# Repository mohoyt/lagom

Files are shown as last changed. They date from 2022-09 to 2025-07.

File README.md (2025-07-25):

# lagom
Lagom is an easy to build 65% keyboard using only through hole components. It uses a separate microcontroller (like the Pro Micro, Elite C or something RP2040 based) to enable flexibility in firmware and connectivity and to further simplify the soldering experience (no more tricksy USB ports). Demultiplexers and a custom matrix are used to enable the size and features of the board with only the pinouts of a pro micro. 

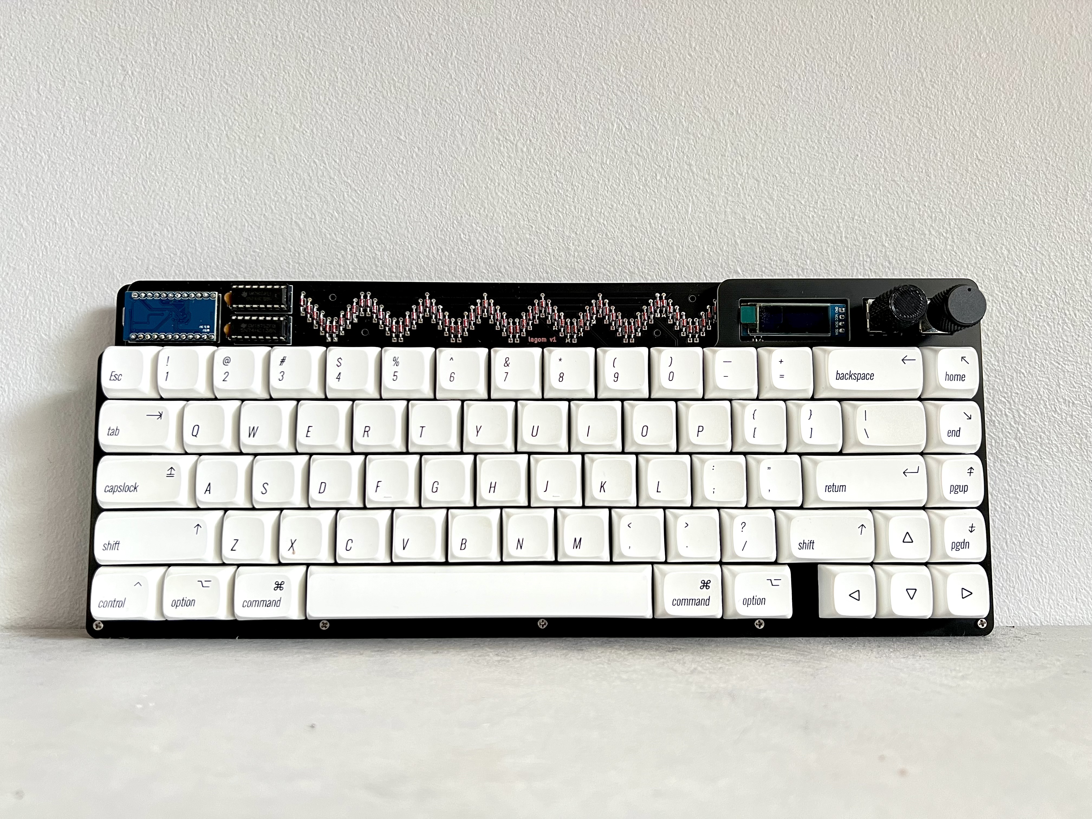
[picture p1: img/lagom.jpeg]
lagom


**Lagom kits are available for sale at [sthlmkb.com](https://sthlmkb.com/shop/lagom-keyboard-kit/)**

[License](LICENSE)

Lagom is licensed under the [Creative Commons Attribution-NonCommercial 4.0 International license](https://creativecommons.org/licenses/by-nc/4.0/). This design as it stands in this repository may be freely reproduced, modified, and manufactured for PERSONAL USE ONLY and may not be reproduced in physical form for public sale. 

## Features
* Only through hole components for easy soldering
* Separate microcontroller using Pro micro, Elite C, Nice! Nano or equivalent footprint. So micro USB, USB-C or Bluetooth are all options!
* 2 rotary encoders
* OLED screen
* Optional underglow RGB lighting with a WS2812b light strip
* Multiple layout options including ISO, ANSI, split space (2.25u + 1.25u + 2.75u), 7u space, split left shift (1.25u + 1u) and stepped capslock ([layout]("http://www.keyboard-layout-editor.com/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,15&_x:0.25%3B&=2,15&_x:0.25%3B&=0,0%0A%0A%0A%0A%0A%0A%0A%0A%0Ae&=0,1%0A%0A%0A%0A%0A%0A%0A%0A%0Ae%3B&@_y:0.25%3B&=0,0&=0,1&=0,2&=0,3&=0,4&=0,5&=0,6&=0,7&=0,8&=0,9&=0,10&=0,11&=0,12&_w:2%3B&=0,14%0A%0A%0A0,0&=0,15&_x:0.25%3B&=1,0%0A%0A%0A%0A%0A%0A%0A%0A%0Ae&=1,1%0A%0A%0A%0A%0A%0A%0A%0A%0Ae%3B&@_w:1.5%3B&=1,0&=1,1&=1,2&=1,3&=1,4&=1,5&=1,6&=1,7&=1,8&=1,9&=1,10&=1,11&=1,12&_w:1.5%3B&=1,13%0A%0A%0A1,0&=1,14%3B&@_w:1.75%3B&=2,0&=2,1&=2,2&=2,3&=2,4&=2,5&=2,6&=2,7&=2,8&=2,9&=2,10&=2,11&_w:2.25%3B&=2,13%0A%0A%0A1,0&=2,14%3B&@_w:2.25%3B&=3,0%0A%0A%0A2,0&=3,2&=3,3&=3,4&=3,5&=3,6&=3,7&=3,8&=3,9&=3,10&=3,11&_w:1.75%3B&=3,12&=3,13&=3,14%3B&@_w:1.25%3B&=4,0%0A%0A%0A3,0&_w:1.25%3B&=4,1%0A%0A%0A3,0&_w:1.25%3B&=4,2%0A%0A%0A3,0&_w:6.25%3B&=4,6%0A%0A%0A3,0&_w:1.25%3B&=4,10%0A%0A%0A3,0&_w:1.25%3B&=4,11%0A%0A%0A3,0&_x:0.5%3B&=4,12&=4,13&=4,14%3B&@_y:0.5&w:1.25%3B&=4,0%0A%0A%0A3,1&_w:1.25%3B&=4,1%0A%0A%0A3,1&_w:1.25%3B&=4,2%0A%0A%0A3,1&_w:2.25%3B&=4,4%0A%0A%0A3,1&_w:1.25%3B&=4,6%0A%0A%0A3,1&_w:2.75%3B&=4,8%0A%0A%0A3,1&_w:1.25%3B&=4,10%0A%0A%0A3,1&_w:1.25%3B&=4,11%0A%0A%0A3,1%3B&@_y:-0.25&x:15&w:1.25&h:2&w2:1.5&h2:1&x2:-0.25%3B&=2,13%0A%0A%0A1,1%3B&@_y:-0.75&w:1.5%3B&=4,0%0A%0A%0A3,2&=4,1%0A%0A%0A3,2&_w:1.5%3B&=4,2%0A%0A%0A3,2&_w:7%3B&=4,6%0A%0A%0A3,2&_w:1.5%3B&=4,11%0A%0A%0A3,2%3B&@_y:-0.25&x:14%3B&=2,12%0A%0A%0A1,1%3B&@_w:1.25%3B&=3,0%0A%0A%0A2,1&=3,1%0A%0A%0A2,1&_x:9.75%3B&=0,13%0A%0A%0A0,1&=0,14%0A%0A%0A0,1"))
* Open and visible components (in the style of Plaid, Romac etc)
* Simple, beautiful and flexible sandwich case out of FR4 (pcb material)

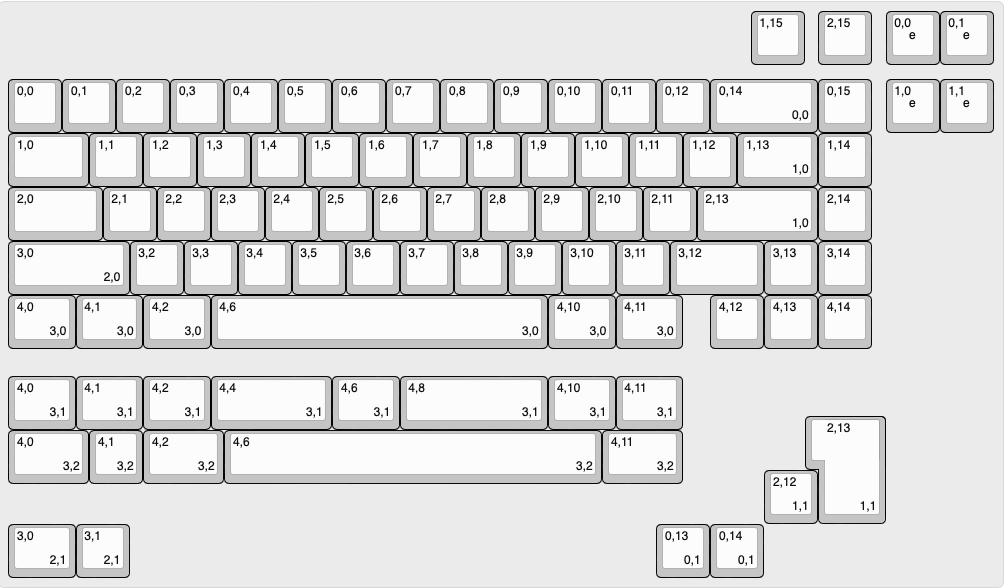
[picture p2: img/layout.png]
lagom layout


## Components required 
* PCB
* FR4 Switch plate
* FR4 Base 
* Controller (I used a Pro Micro in the guide but anything that shares the footprint and pinout will be fine e.g. Elite C, Nice! Nano, or something RP2040 powered!)
* Diodes 1N4148 (74)
* 0.1μF Capacitor (2)
* 16 pin IC socket (2)
* IC (74HC138N) demultiplexer (2)
* Switches (5 pin MX footprint) (up to 72 depending on layout)
* Rotary encoders (2)
* Rotary encoder knobs (2)
* 0.91" OLED screen
* 10mm M2 Standoffs (9 required if mounting the base to the plate)
* 6mm x M2 screws for attaching the standoffs to the plate/base (2 per standoff so 18 total)
* Acrylic cover for the components at the top (optional, not included)
* Stabilisers (PCB mount) (5 x 2u or 3 x 2u + 6.25u or 3 x 2u + 7u depending on layout)
* Rubber feet for the base

[Build guide available here](build_guide.md)

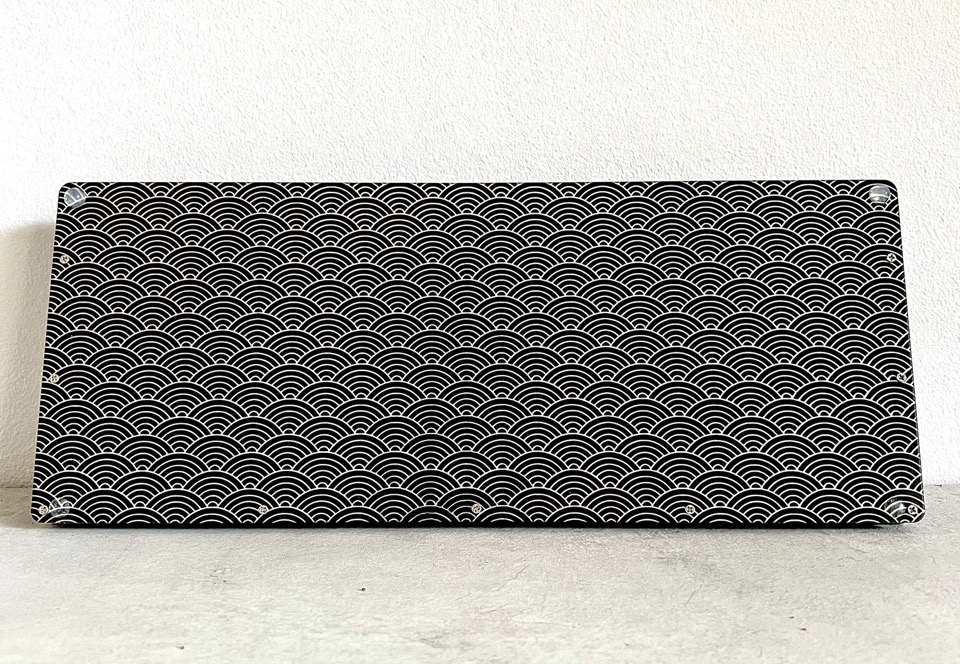
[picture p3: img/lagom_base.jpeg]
lagom base


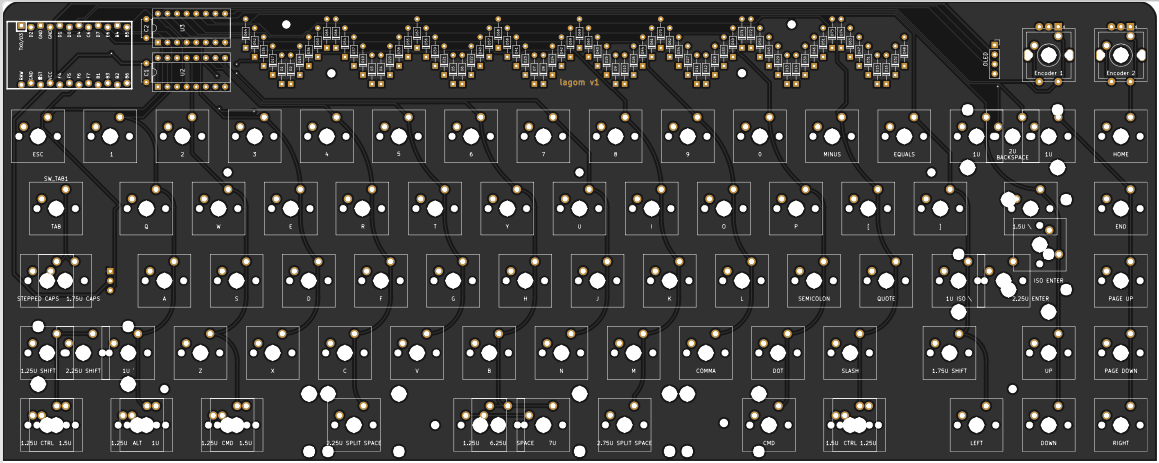
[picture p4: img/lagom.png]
lagom lagom pcb


## Dimensions
* PCB: 305.6mm x 121.78mm
* Plate: 319.925mm x 128.925mm (102.662mm height at the lower section)
* Base: 319.925mm x 128.925mm 

## Known issues 
None yet! 

## Where to buy
Lagom kits are available for sale exclusively at [sthlmkb.com](https://sthlmkb.com/shop/lagom-keyboard-kit/)

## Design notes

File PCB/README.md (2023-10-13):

# lagom PCBs
Lagom is an easy to build 65% keyboard using only through hole components. It uses a separate microcontroller (like the Pro Micro, Elite C or something RP2040 based) to enable flexibility in firmware and connectivity and to further simplify the soldering experience (no more tricksy USB ports). Demultiplexers and a custom matrix are used to enable the size and features of the board with only the pinouts of a pro micro. 

lagom

**Lagom kits are available for sale at [sthlmkb.com](https://sthlmkb.com/shop/lagom-keyboard-kit/)**

[License](LICENSE)

Lagom is licensed under the [Creative Commons Attribution-NonCommercial 4.0 International license](https://creativecommons.org/licenses/by-nc/4.0/). This design as it stands in this repository may be freely reproduced, modified, and manufactured for PERSONAL USE ONLY and may not be reproduced in physical form for public sale. 

## Designs that are here:
* Lagom (i.e this directory) - this is the main PCB
* Lagom Plate (`lagom_plate`) - this is the plate that holds the switches and goes above the PCB
* Lagom Base (`lagom_base`) - this is the base of the board and goes below the PCB
* Lagom Window (`lagom_window`) - this is an optional design for an acrylic window that covers the diodes and the controller

## Some useful images/documentation:

lagom layout

This the key layout and all option layouts exported from keyboard-layout-editor

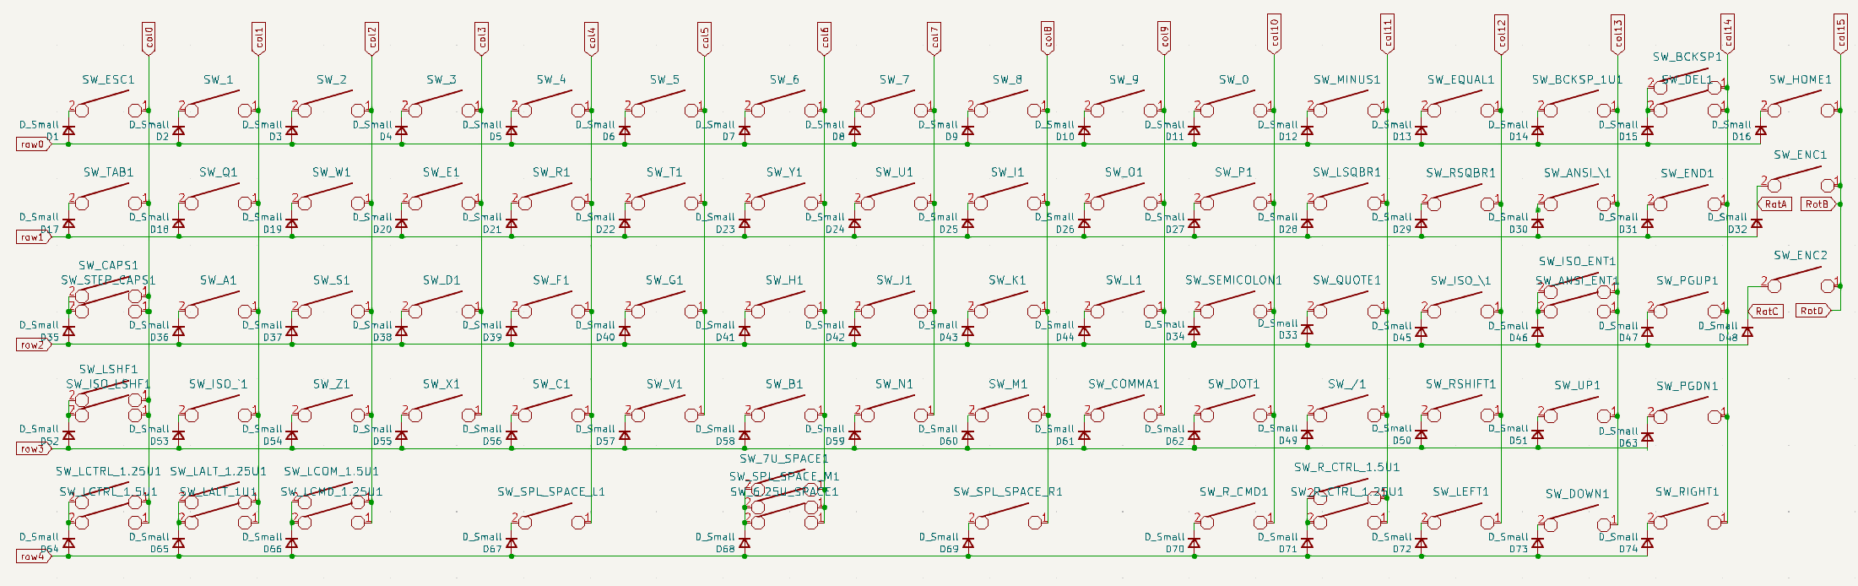
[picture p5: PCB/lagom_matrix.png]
lagom matrix


This the layout of the matrix used

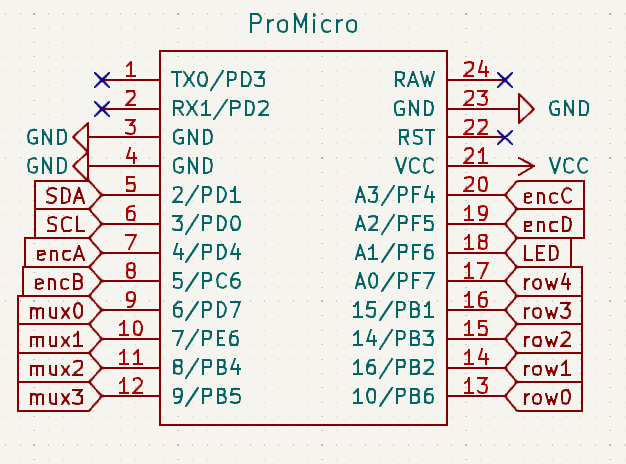
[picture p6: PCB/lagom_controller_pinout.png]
controller pinout


This the pinout of the pro micro or pro micro compatible controller

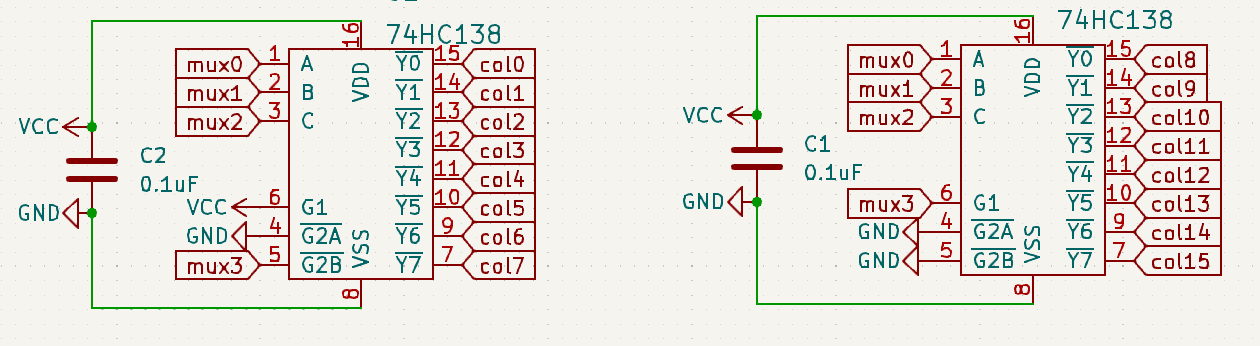
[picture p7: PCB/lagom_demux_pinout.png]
demux pinout


This is the pinout of the demuxes used in Lagom to enable all the columns to work on a pro micro pinout

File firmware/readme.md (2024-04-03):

# lagom

Lagom is an easy to build 65%ish keyboard using only through hole components. It uses a separate microcontroller (like the Pro Micro or Elite C) to enable flexibility in connectivity and to further simplify the soldering experience (no more tricksy USB ports).

* Keyboard Maintainer: [mohoyt](https://github.com/mohoyt)
* Hardware Supported: lagom, Pro Micro, Elite-C, Puchi-C, Nice!Nano and more...
* Hardware Availability: [sthlm kb](https://sthlmkb.com)

Make example for this keyboard (after setting up your build environment):

    make sthlmkb/lagom:default

See the [build environment setup](https://docs.qmk.fm/#/getting_started_build_tools) and the [make instructions](https://docs.qmk.fm/#/getting_started_make_guide) for more information. Brand new to QMK? Start with our [Complete Newbs Guide](https://docs.qmk.fm/#/newbs).

NB If you want to flash a Vial compatible image then you have to use the [Vial fork of QMK](https://github.com/vial-kb/vial-qmk) and ensure that you have all the Vial specific files present (but these should already be there if you're using on the Vial keymaps as a starting point).

Alternatively flash one of the precompiled hexes. There's a few options:
* One's a Vial compatible image one with bongocat
* Another's a Vial image with a WPM graph on it

The .hex file is if you're using an Atmel chip (like a traditional Pro Micro). The uf2 files are for a RP2040 style pro micro like the Helios. 

## RP2040 Flashing

If you are compiling your own firmware for a RP2040 variant of a Pro Micro then the easiest way of converting the output from .hex to .uf2 is to use the convert feature of QMK [more details here](https://docs.qmk.fm/#/feature_converters?id=overview). 

For example you would flash one with a Helios style pin out like this:
```
make sthlmkb/lagom:vial-wpmhud CONVERT_TO=helios
```

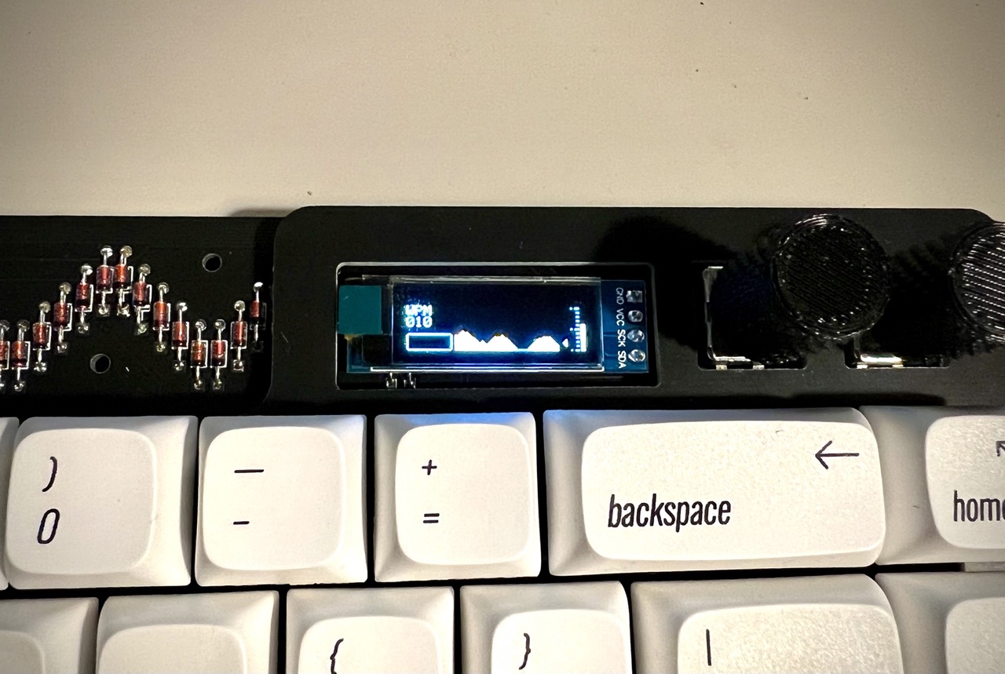
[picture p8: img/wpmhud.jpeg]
wpm graph lagom


## RGB Lighting

It is possible to add RGB lighting to the Lagom. There's a couple changes that you need to make to info.json to make it happen before recompiling the firmware. These changes are:
* Adding `"rgblight": true` to the feature section
* Adding a `rgblight` and `ws2812` section. More info [here](https://docs.qmk.fm/#/feature_rgblight) too.
```    
"rgblight": {
        "led_count": 11,
        "sleep": true,
        "hue_steps": 10,
        "saturation_steps": 10,
        "brightness_steps": 10,
        "animations": {
            "rainbow_mood": true,
            "static_gradient": true
        }
       },
    "ws2812": {
        "pin": "F6"
        }
```
* You'll then need to assign some keys to toggle on the RGB and change modes etc. This is easiest done in Vial if you've flashed a Vial compatible image. 
* Bear in mind that the RGB feature takes up some space so you may run out of space if you're compiling this for a Pro Micro

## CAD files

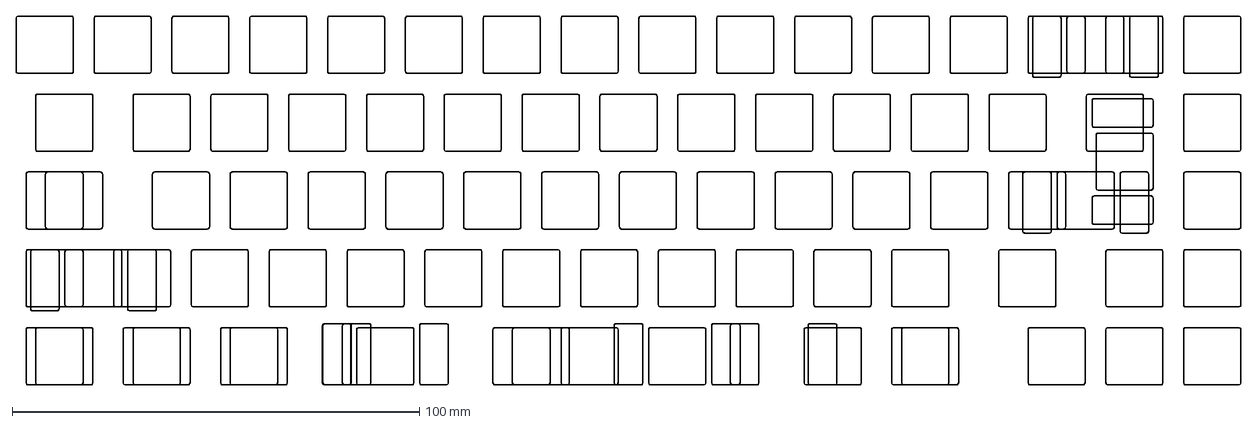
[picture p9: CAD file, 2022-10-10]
PCB/lagom-plate-orig.dxf
300.5 x 90.4 mm

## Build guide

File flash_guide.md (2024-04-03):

# Pro Micro Microcontroller Flashing Guide

You’ve built your keyboard and now you want to make it work. To do this you’ll have to flash your microcontroller.

The exact specfics of how you do this depend on the microcontroller that you’re using, so take a look at their specific documentation. I will go through the process of flashing a Pro Micro conroller here. The instructions assume that you’re flashing a ‘traditional’ atmel based Pro Micro, but if you are flashing a RP2040 variant then scroll down to the lower section of this page.

## Atmel ‘Traditional’ Pro Micro Flashing

1. You’ll need a compiled firmware file. This is something that you might have downloaded from where you bought your keyboard, or something that you configured and built yourself. It’s a file that has a .hex file format. We have precompiled firmware files for Lagom [here](https://github.com/mohoyt/lagom/releases) and some notes on compiling [here](https://github.com/mohoyt/lagom/firmware).

2. Download and install QMK Toolbox from their Github page: https://github.com/qmk/qmk_toolbox

3. Open QMK Toolbox and connect your keyboard or controller to your computer over USB. You might see something in the QMK console when you connect it, but not always.

4. Press open at the top of the QMK configurator window and choose the .hex file that you want to flash to your microcontroller. Precompiled (and Vial compatible) hex files for the Lagom are available [here on our Github](https://github.com/mohoyt/lagom/releases). If you want to be able to configure your keyboard using Vial (recommended) then make sure to flash one of the vial hex files. Ensure that the file that you’re trying to flash has the file format .hex as sometimes browsers will download these files oddly. 

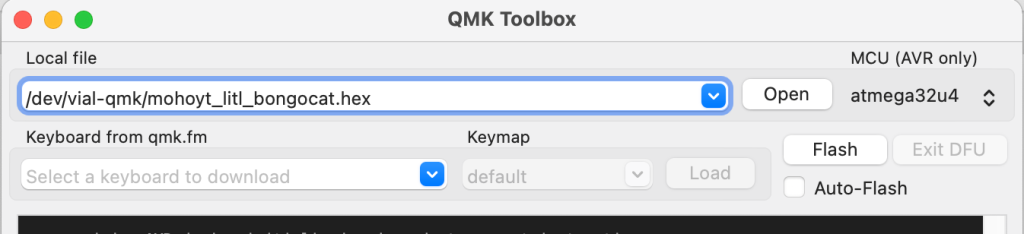
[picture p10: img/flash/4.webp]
qmk toolbox


5. Ensure that you have the correct MCU chosen at the top right of the QMK Toolbox window. For a Pro Micro it is an atmega32u4

6. Now comes the slightly tricky bit. You’ll need something metal to short two of the pins on the microcontroller. You can use pliers, a piece of wire or even a pen. You want to briefly connect and then disconnect the RESET and the GROUND pins of the Pro Micro. These are the second and third pins on the right hand side when the components are facings towards you and the usb port is facing up.

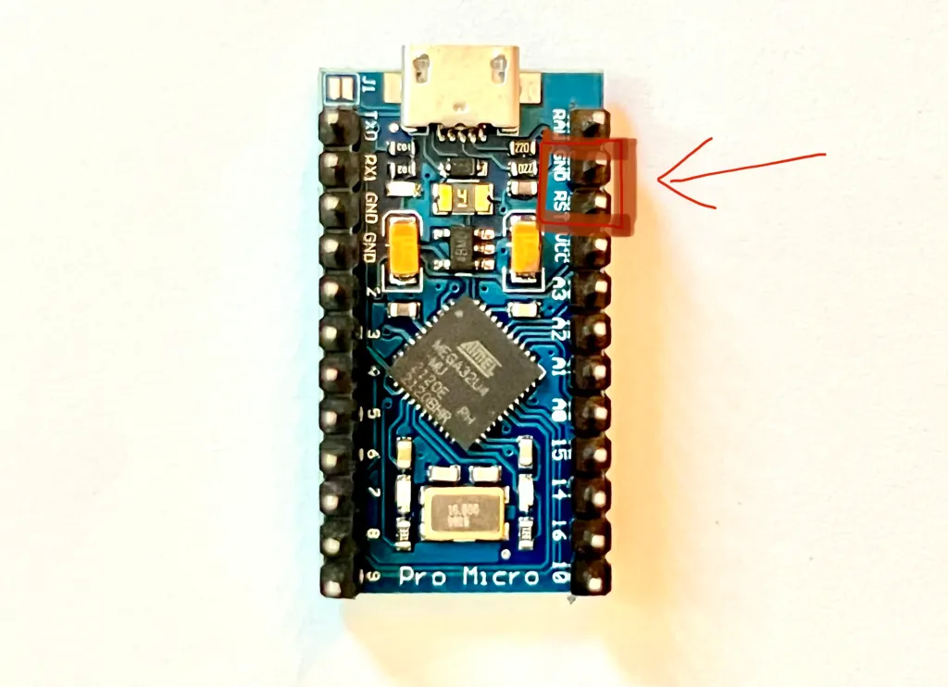
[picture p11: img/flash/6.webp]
pro micro pins


If you’re flashing the controller once it’s already soldered on the keyboard then you will need to short the same pins but likely from the other side. It’s the two pins pictured in the image below.

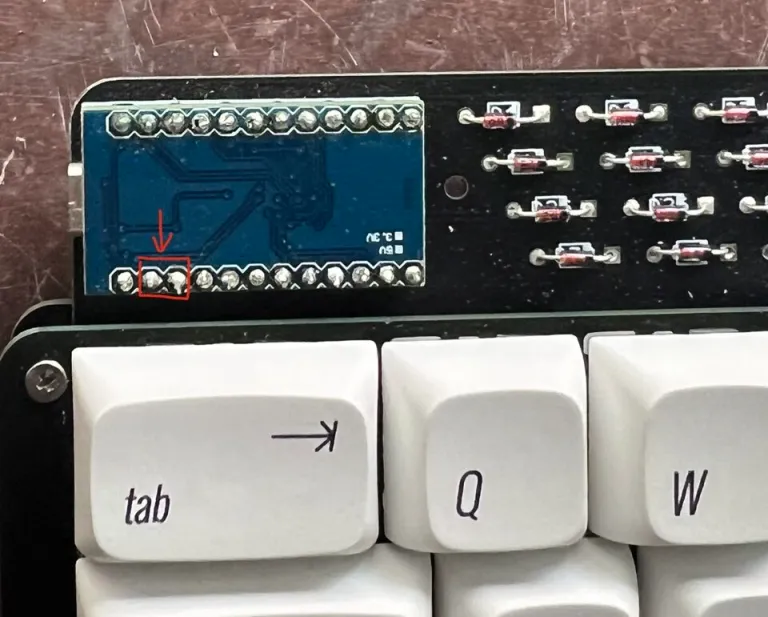
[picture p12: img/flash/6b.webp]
pro micro pins on board


7. If you’ve successfully connected the pins and then disconnected them you should see a yellow line in the QMK Toolbox console like this. The line might say something slightly different depending on your controller.

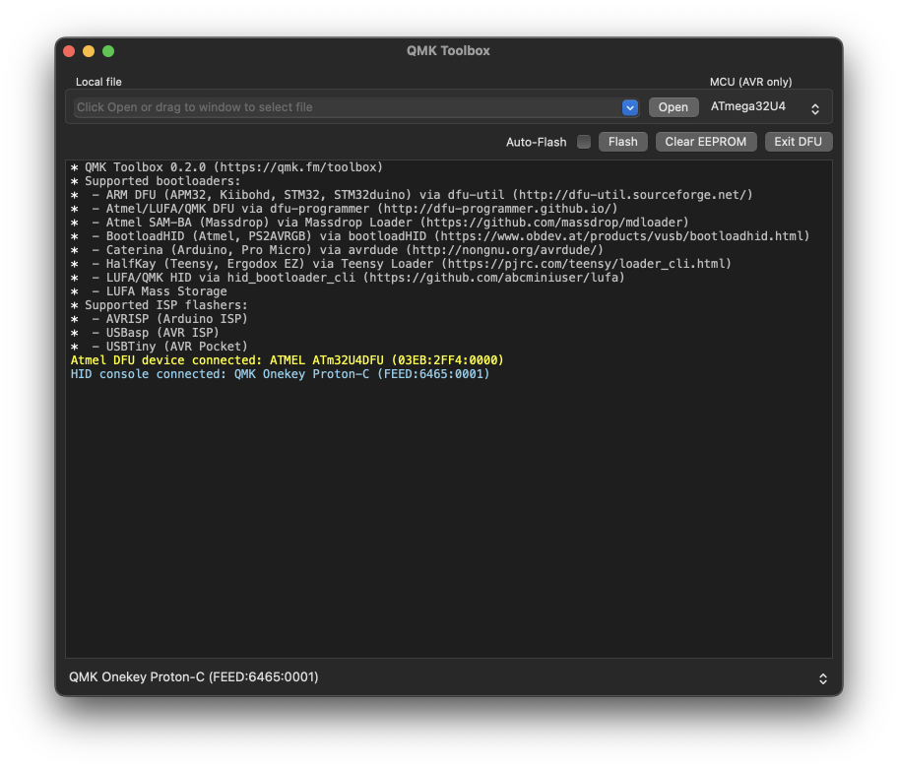
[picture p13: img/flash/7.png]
qmk toolbox screenshot


8. Once you see the yellow line, you need to press Flash within 5 seconds. There will be lots of text rendered on the console when you do this, but it will ultimately say something like avrdude done. Thank you  and then will print another yellow disconnect line if it succeeds.

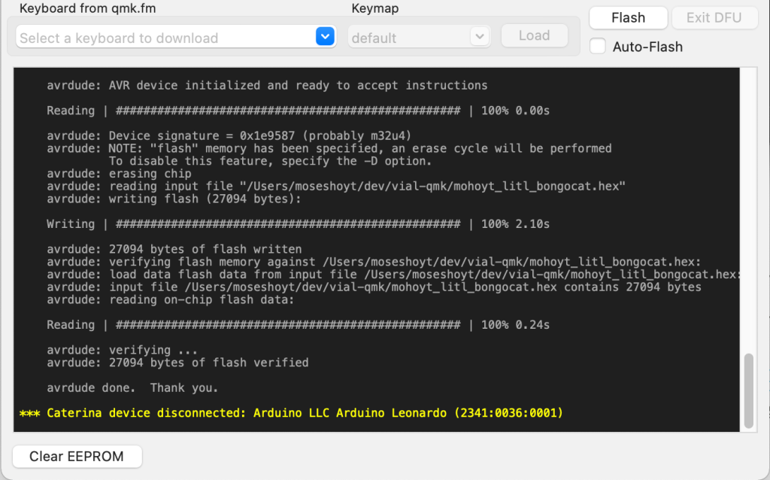
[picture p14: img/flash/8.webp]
successful flash


9. If you’ve flashed the QMK firmware then your keyboard should be good to go right away. If you flashed the Vial firmware then your keyboard should work right away too, but if you want to configure layers then you will have to download Vial.

## RP2040 Pro Micro Flashing

1. You’ll need a compiled firmware file. This is something that you might have downloaded from where you bought your keyboard, or something that you configured and built yourself. It’s a file that has a .uf2 file format. We have precompiled firmware files for Lagom [here](https://github.com/mohoyt/lagom/releases) and some notes on compiling [here](https://github.com/mohoyt/lagom/firmware).

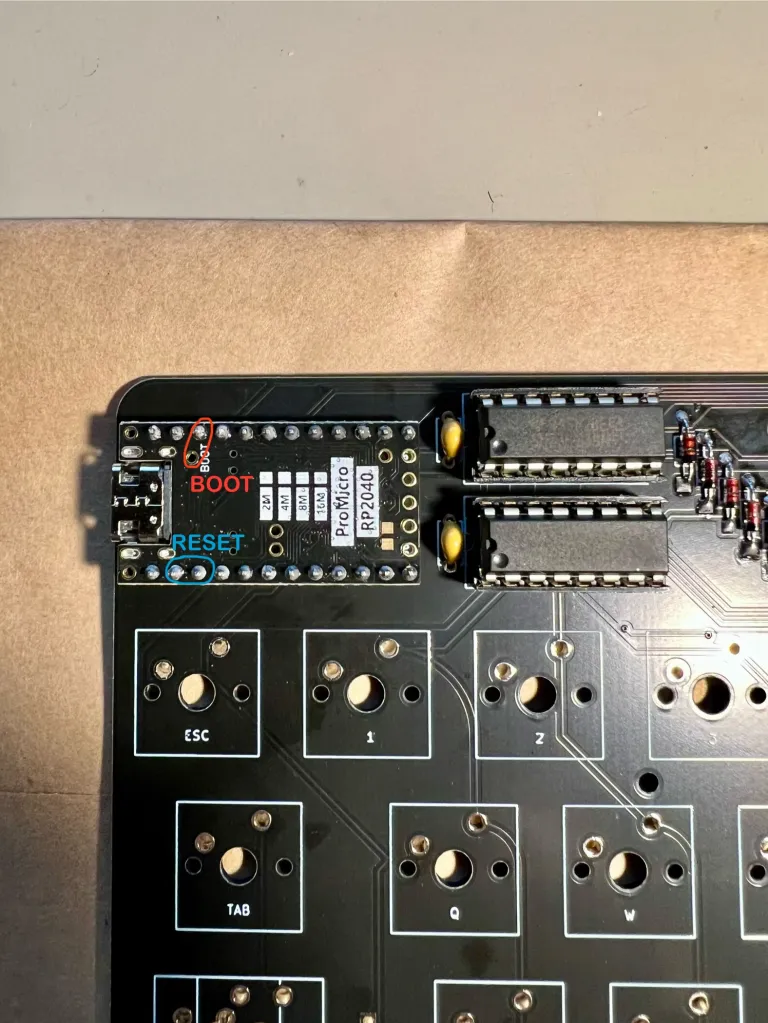
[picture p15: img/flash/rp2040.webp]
rp2040 flash


2. You now need to plug it in with USB to your computer and get the RP2040 Pro Micro to enter bootloader mode.

The RP2040 will be in bootloader mode when a RPI-RP2 volume appears on your computer.

There are a number of ways of doing this. Ranked from easy to most tricky:

* If you have a brand new RP2040 Pro Micro, many times it will start up for the first time in bootloader mode. But if not, read on.
* If you have a built keyboard – hold down the bootloader key while you plug in the keyboard.
    * This is the easiest way to get into the bootloader. But it only works if the controller is already flashed with QMK or Vial. The key you would need to hold down is the key is the first key on the first column. 99% of the time that’s the escape key.
* If you have the Pro Micro unconnected to a keyboard or the reset button easily accessible – double tap the reset button on the Pro Micro RP2040.
    * Like the method above this only works if it is already flashed with QMK. This is a little bit more annoying than holding down a key because you may need to open your keyboards case to gain access to your reset switch.
    * If there is no reset button then you can short the RST pin and a GND pin twice in quick succession.
* Hold down the boot button on the Pro Micro RP2040 while you plug in your keyboard.
    * The Pro Micro RP2040 has 2 buttons on it, boot and reset. Hold boot in while connecting via USB
    * You can also short the BOOT pin and a GND pin while plugging in the keyboard too
* Hold down boot switch while you tap your reset switch.
    * If you have access to both BOOT and RESET switches (e.g. if you’ve not soldered on the Pro Micro yet) you simply hold down the boot switch while you tap and let go of the reset switch.
    * You can also short and hold the BOOT pin and a GND pin while shorting RST and a GND pin to achieve the same thing.

*You will know that these work when a RPI-RP2 drive is mounted on your computer.*

3. Drag the .uf2 firmware file to the RPI-RP2 drive that has now been mounted on your computer. Once the file is copied the drive should automatically disconnect.

4. You may have to unplug and re plug in the controller, but it should now be recognised to you computer as a keyboard (or input device) and you should be able to type on it.

## You did it! Nice one. 

Any feedback or challenges with the build process? Get in touch with us at hej at sthlmkb.com

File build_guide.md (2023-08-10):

# Lagom build guide

lagom

## Components required 

* PCB
* FR4 Switch plate
* FR4 Base 
* Controller (I used a Pro Micro in the guide but anything that shares the footprint and pinout will be fine e.g. Elite C, Nice! Nano, or something RP2040 powered!)
* Diodes 1N4148 (74)
* 0.1μF Capacitor (2)
* 16 pin IC socket (2)
* IC (74HC138N) demultiplexer (2)
* Switches (5 pin MX footprint) (up to 72 depending on layout)
* Rotary encoders (2)
* Rotary encoder knobs (2)
* 0.91" OLED screen
* 10mm M2 Standoffs (9 required if mounting the base to the plate)
* 6mm x M2 screws for attaching the standoffs to the plate/base (2 per standoff so 18 total)
* Acrylic cover for the components at the top (optional, not included)
* Stabilisers (PCB mount) (5 x 2u or 3 x 2u + 6.25u or 3 x 2u + 7u depending on layout)
* Rubber feet for the base

## You will also need

* Soldering iron
* Solder
* Diode bender (helpful but not required, I used [this one](https://www.printables.com/model/23523-1n4148-diodes-bending-jig))
* A small amount of electrical tape for the backside of the OLED

## Before you begin!

Please double check everything and that you have all the parts! If you ordered a kit there is a very slim chance we forgot something or that your order is wrong; in the case this is true, please reach out via email at hej at sthlmkb.com and we will work with you to make it right. 

Due to the DIY nature of this hobby, as soon as a soldering iron touches or other modifications happen to the board, I am no longer able to issue a refund/replacement. 

Note about this guide: For this guide, I am building a board with a Pro Micro, 2 encoders and an OLED - yours may differ. You are free to adjust or skip steps if they do not apply to your scenario.

All that being said, let's get started!

## Step by step

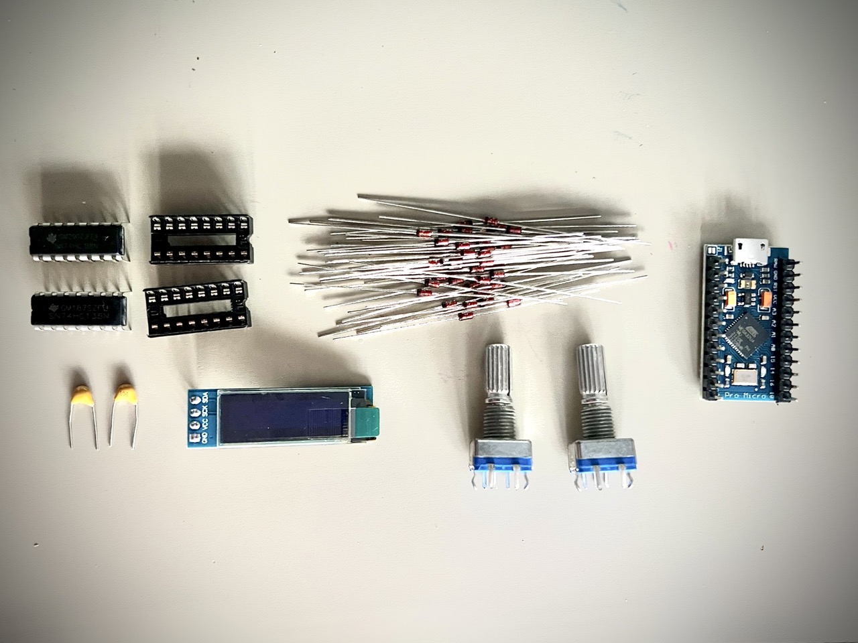
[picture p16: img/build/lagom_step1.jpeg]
components

1. Check that you have all the components you need.

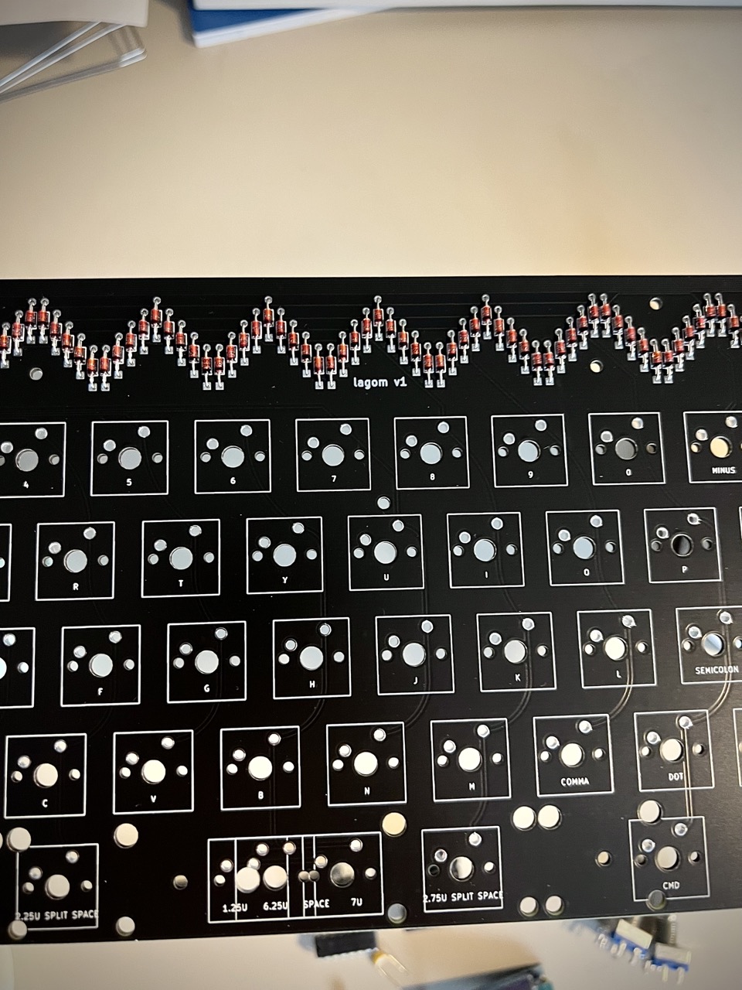
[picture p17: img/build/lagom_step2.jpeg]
diodes

2. Start by bending all the diodes (I used the 3d printed diode bender above). And then place them in the sockets, ensuring that you have the *correct orientation*, the black line on the diode should match the white lines on the board. I then placed some tape over the diodes to hold them in place while I flipped over the board to solder them.

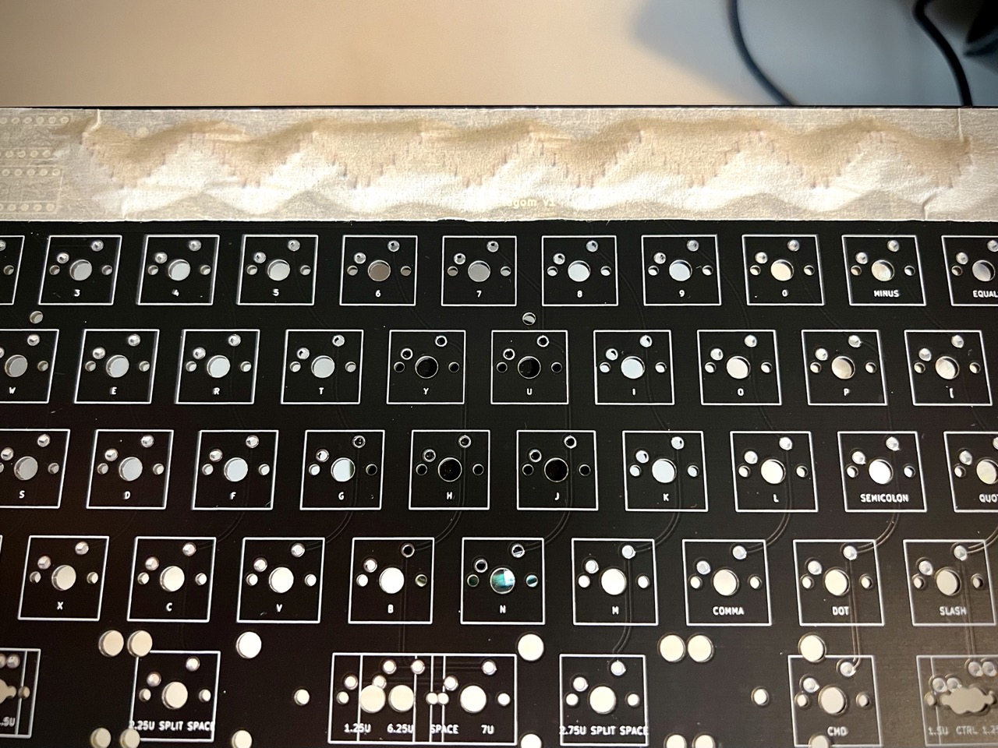
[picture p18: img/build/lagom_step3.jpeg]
masking tape on diodes

3. Solder the diodes on (I soldered on the underside of the board) and trim their legs once the solder has cooled

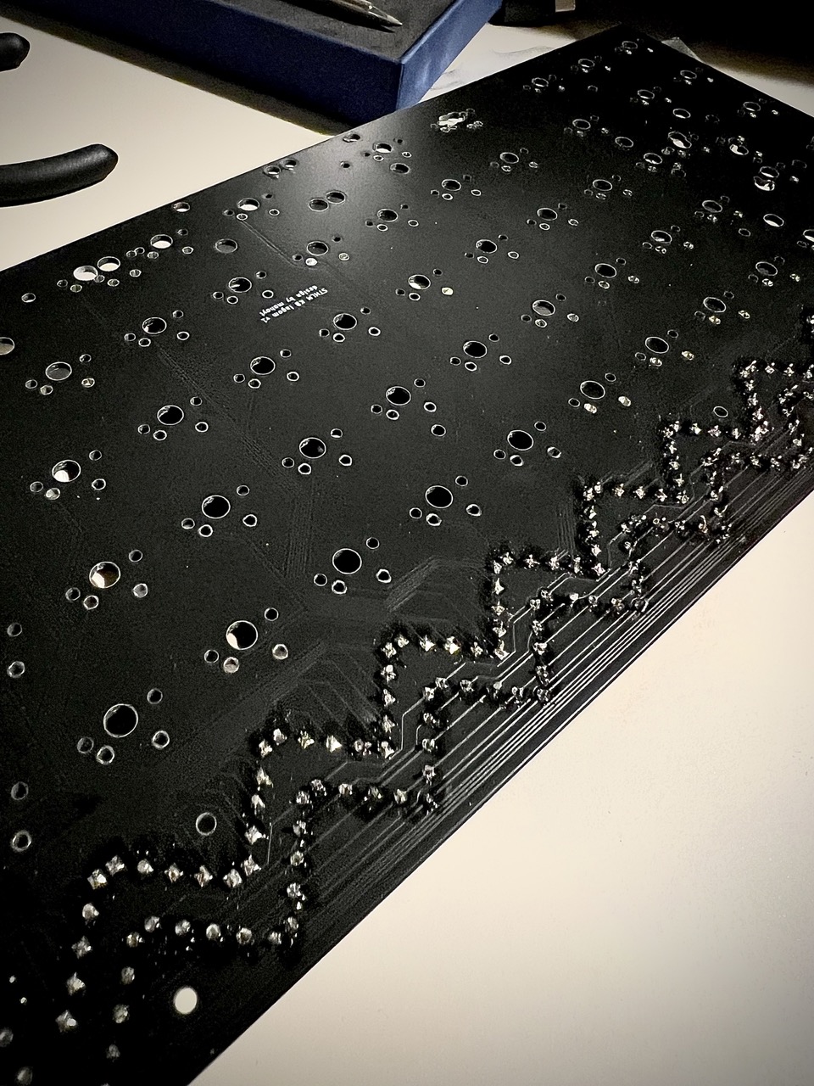
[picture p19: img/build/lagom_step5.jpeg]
trimmed legs

4. Solder the 2 capacitors to the PCB. They should sit on the top side of the PCB (like the diodes). Orientation does not matter with them.

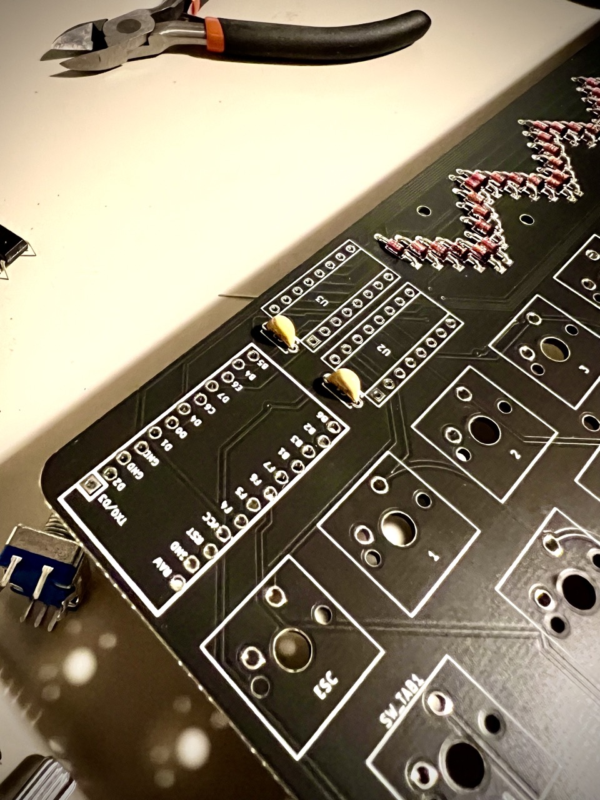
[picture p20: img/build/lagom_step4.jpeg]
capacitors

5. Solder the 2 IC sockets to the PCB. They have a notch on them and the notch should be aligned with the notch on the footprint (pointing towards the capacitors). Do *not* place the ICs in the sockets yet. 

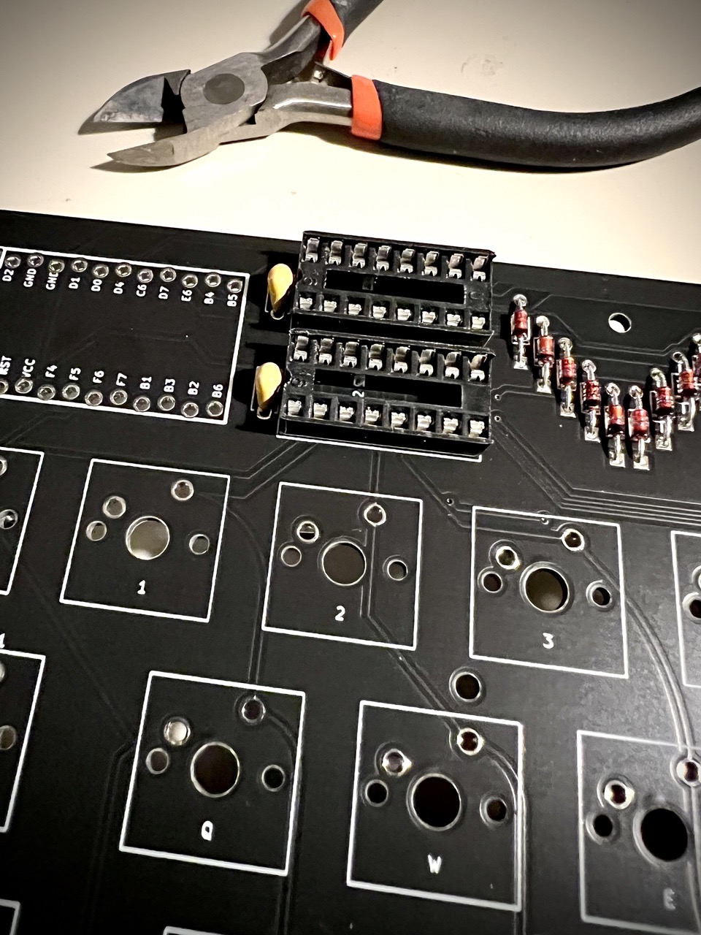
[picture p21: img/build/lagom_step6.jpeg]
ic sockets

6. Solder the two rotary encoders to the board. They should only fit one way, ensure that you don't bend any of the pins when doing so.

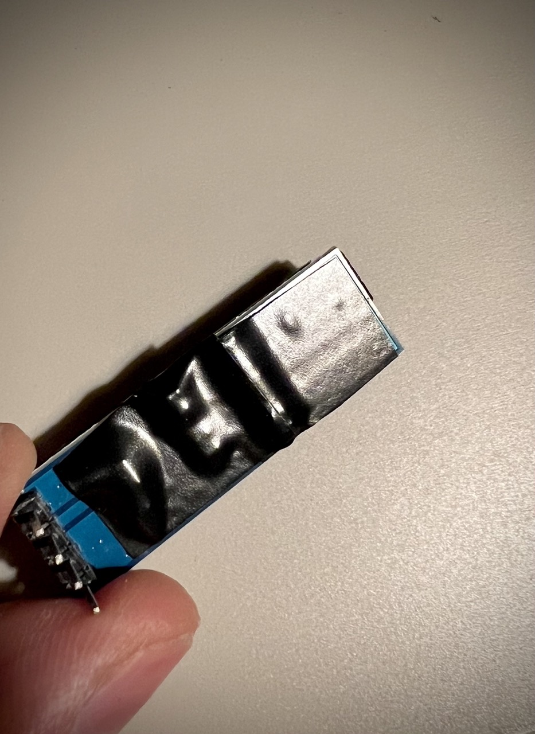
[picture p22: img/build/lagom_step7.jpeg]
oled tape


7. Cut a small section or two of electrical tape and place it on the back of the OLED screen to cover up the resistors and other surface mount components there. This is to ensure that they do not short with the diodes when placed on top of them.
8. Solder the OLED screen in place. The screen should be facing to the left and the ground pin of the OLED should be at the top of the board. The orientation matters here, but realistically it's hard to get it wrong as the encoders will be in the way. If you're planning on adding RGB underglow with a light strip (e.g. a WS2812b compatible one) then this is could be a good time to solder a socket to the 3 holes to make it easier for later (but it's possible to mod this later if you want to). See the image below for an example (excuse the poor soldering). Ensure you get the pins correct when you add an LED strip. 

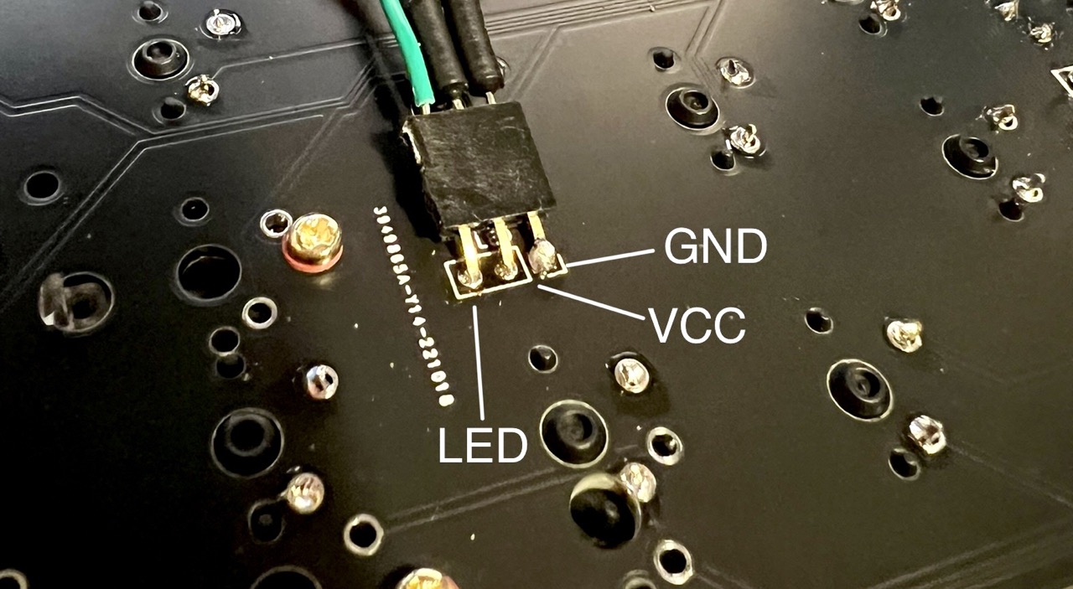
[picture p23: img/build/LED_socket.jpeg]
led socket


9. Flash your controller and check that it is working as expected (e.g. when you plug it into the computer it is recognised as a USB keyboard device). See flashing instructions [here](https://sthlmkb.com/2022/06/flashing-your-microcontroller/) or [here](flash_guide.md).
10. Solder your controller to the board. The board has offset holes so that hotswapping might work, but this didn't go so great in practice so I just soldered my controller on. You are of course very welcome to socket your controller too if you value switchability. I soldered headers onto my controller and then soldered everything onto the PCB and then trimmed the legs on the underside of the PCB. *Orientation matters* here so ensure that you have the controller in the right position. With a pro micro this is facing down so the USB port is wedged between the Pro Micro and the PCB.

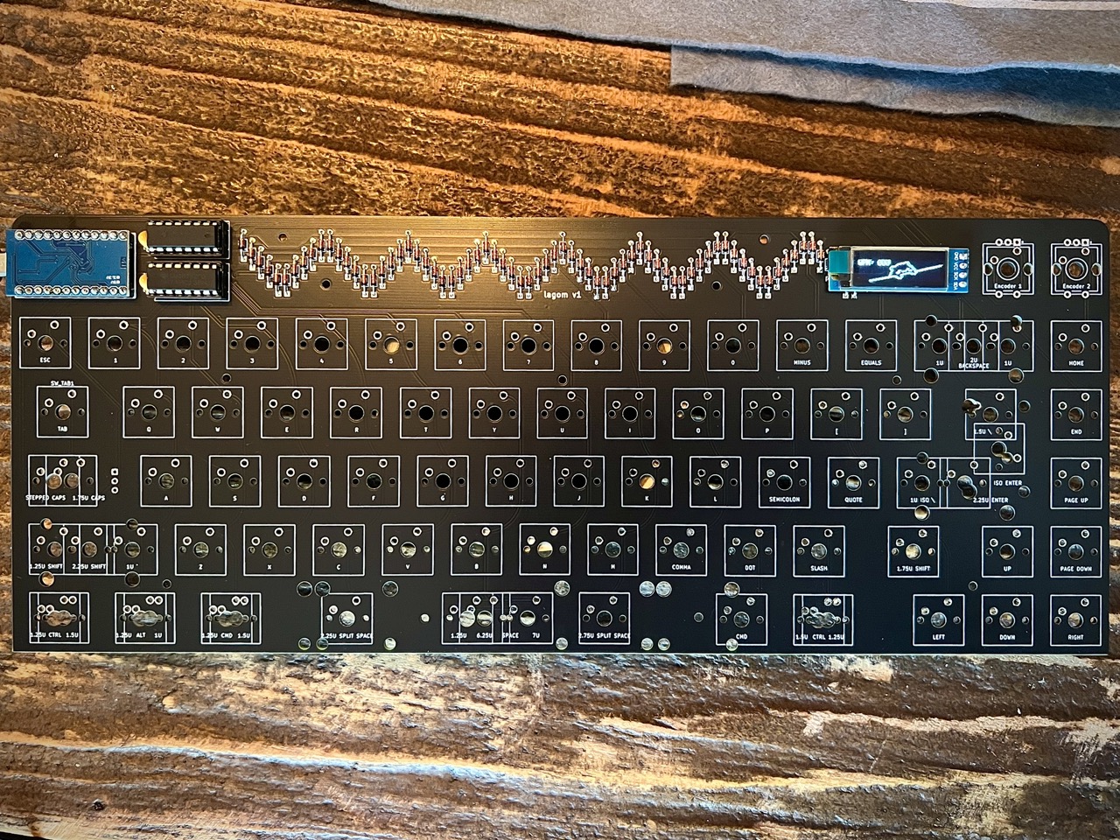
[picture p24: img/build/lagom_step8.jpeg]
testing

11. Insert the ICs into the sockets (be careful of the legs and do not bend them). Now you should be able to plug in your board and test that all keystrokes are recognised. I used a pair of tweezers or a switch to short the switch sockets for this. 	

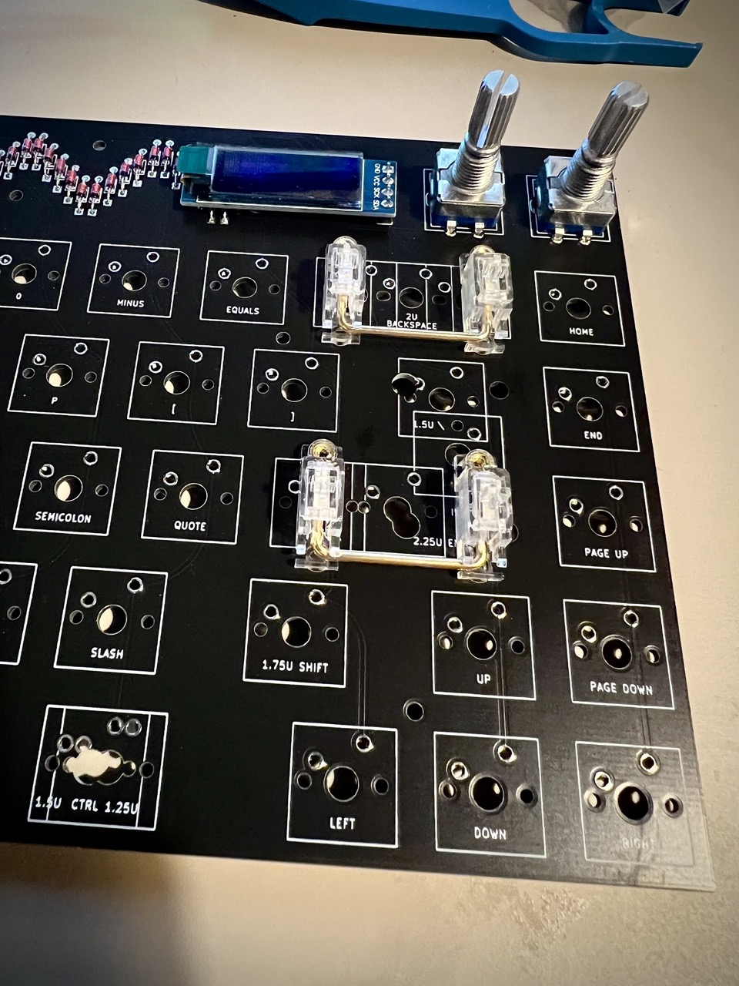
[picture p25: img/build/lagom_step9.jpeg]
stabilisers

12. Add the stabilisers. Hopefully by now you should know what layout you want, but if you don't then now's a good time to choose! I used some Glorious GOAT PCB mounted screw in stabs in the photos. If you want to mod and/or lube your stabs then this is the time!

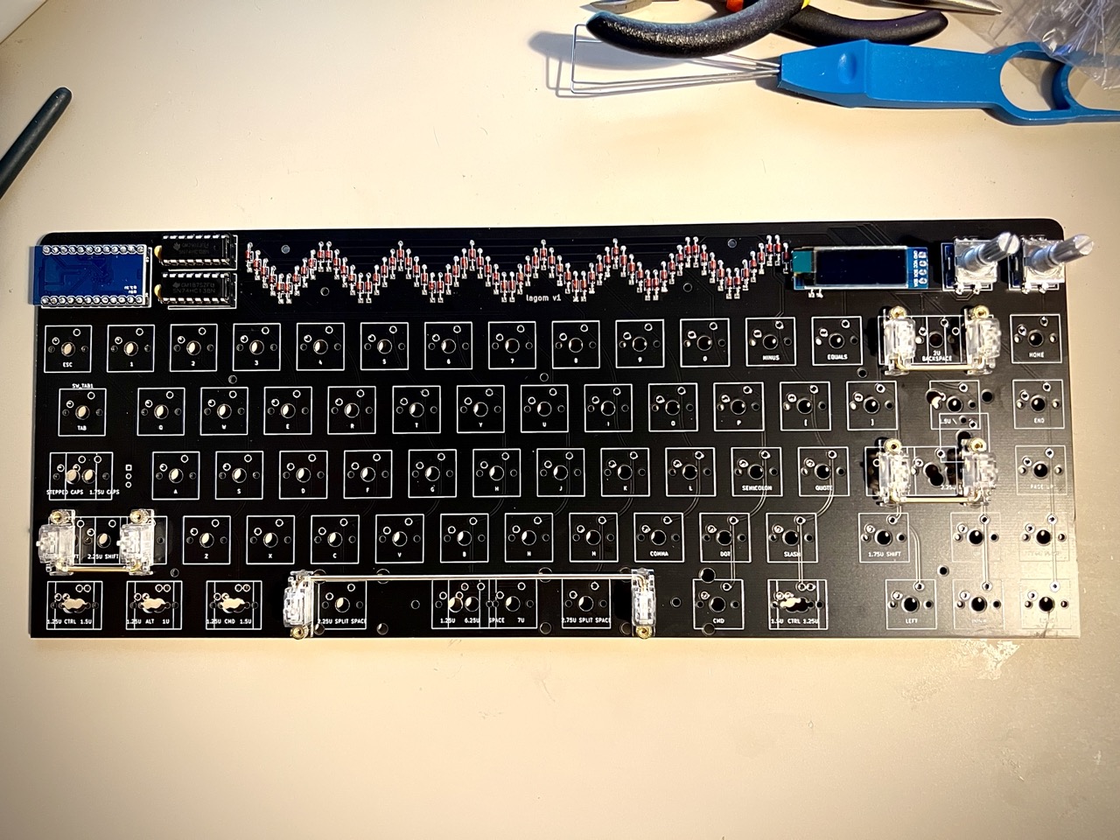
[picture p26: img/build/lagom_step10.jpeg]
all the stabilisers

13. Start by placing a couple switches in the corners of the plate and then attach the plate to the PCB ensuring that you don't bend any pins while doing so. Ensure that the rotary encoders and the OLED screen are fitting correctly once you place the plate on top.

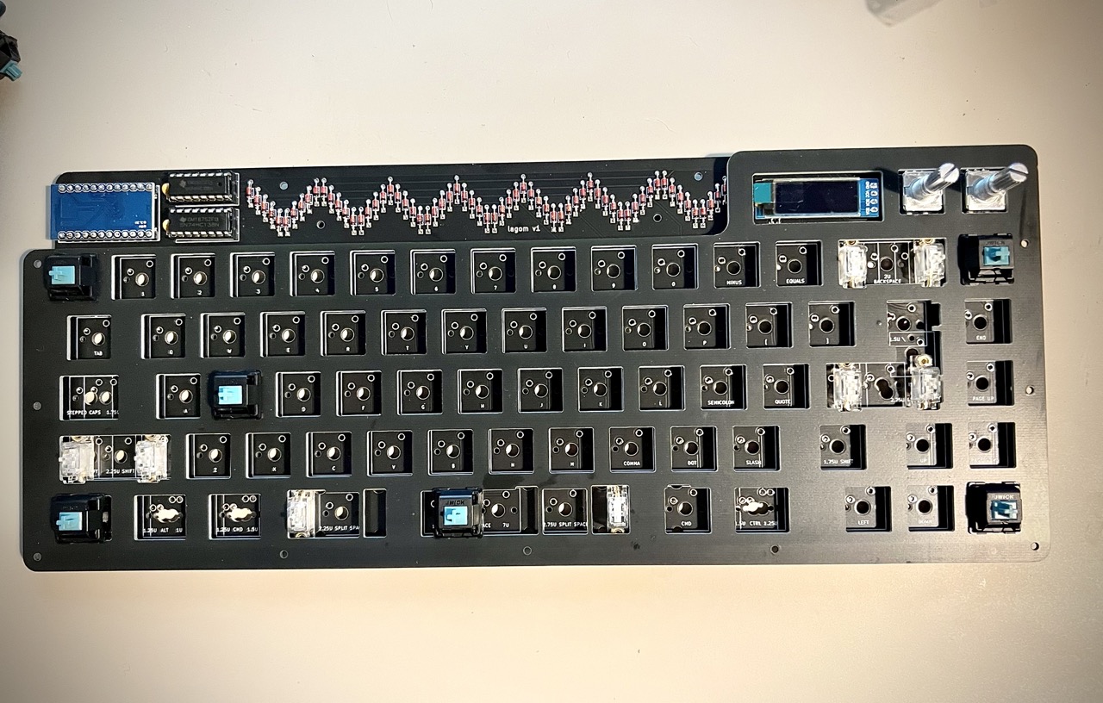
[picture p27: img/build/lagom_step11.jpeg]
plate

14. Continue placing the rest of the switches until all keys are present. I used JWick T1 Tactile switches in the photos and went with the standard ANSI layout with a 6.25u space bar.

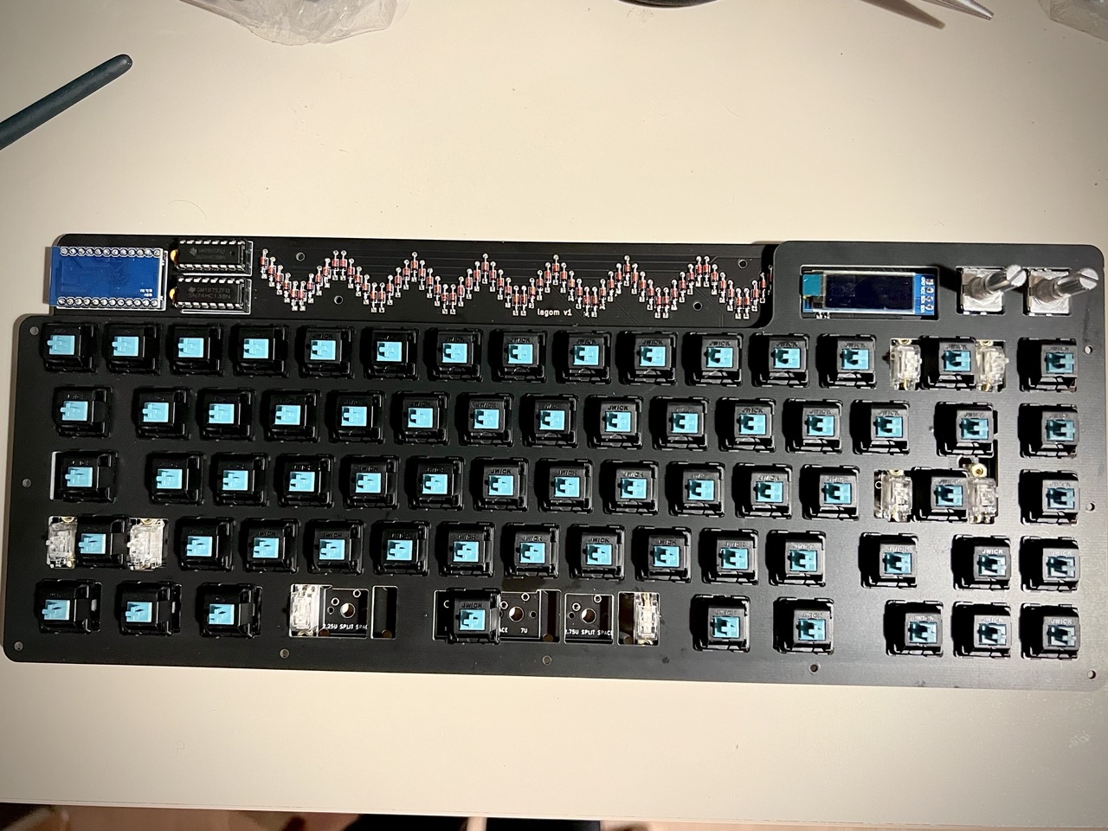
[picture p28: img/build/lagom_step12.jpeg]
all switches added

15. Double check that your stabilisers are all correct (i.e. the wires are seated securely) and lubed as there's no going back once you've soldered switches in. Check again that that none of the switch pins are bent and not poking through the holes. They're a pain to fix once you've started soldering the switches.

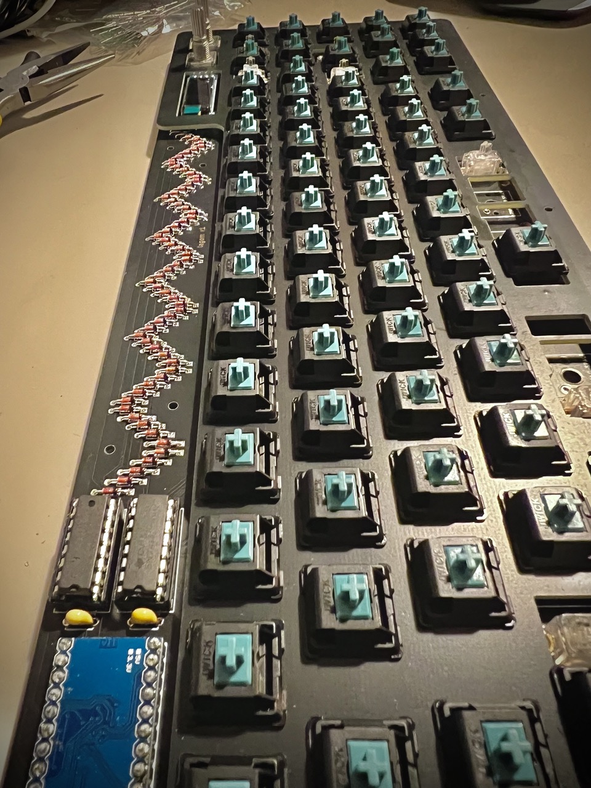
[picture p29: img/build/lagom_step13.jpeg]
side angle switches

16. Start soldering all the switches in place. Double check that you've not missed anything (it's easy to overlook a few switches).
17. Attach the standoffs to the screws on the edges of the switch plate and position the base plate correctly and screw in the screws from the bottom too. Add the rubber bumbers to the base plate in the corners. The larger ones go at the top so that you get a slight  typing angle.
18. Add some keycaps and encoder knobs and *you are done!* Have a test that everything's working as expected and maybe update/flash some new firmware if you feel like it. Enjoy!

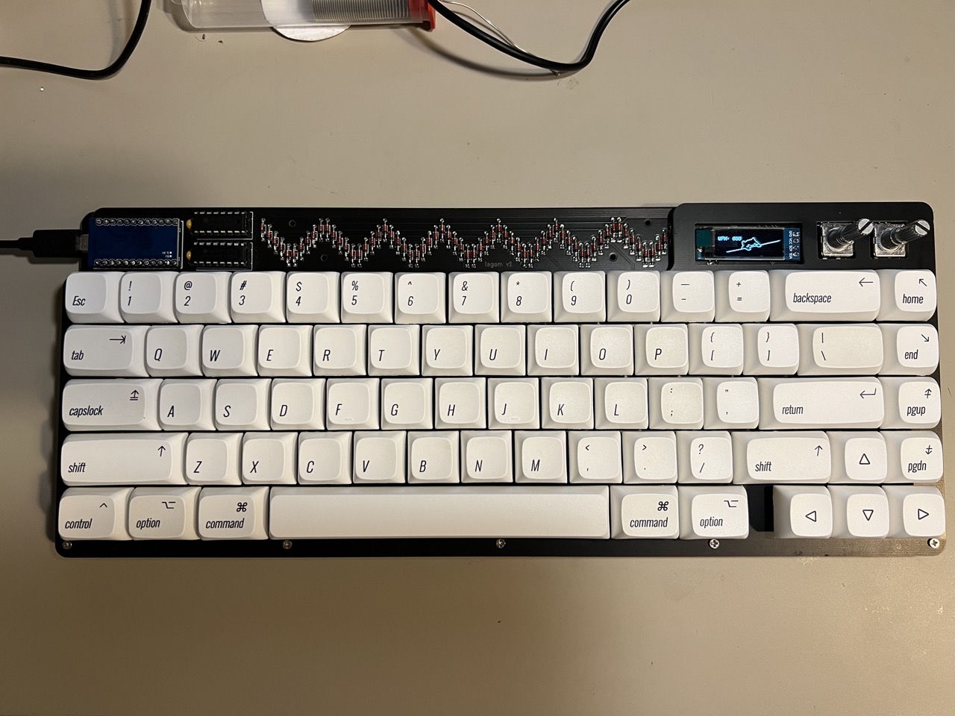
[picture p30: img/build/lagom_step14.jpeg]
lagom complete


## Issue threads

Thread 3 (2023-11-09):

Vial Firmware fails to build

tonykakuuu, 2023-11-09:
Running  `qmk flash -c -kb sthlmkb/lagom -km vial` fails to build.

```
Generating: .build/obj_sthlmkb_lagom_vial/src/default_keyboard.h                                    [OK]
Compiling: keyboards/sthlmkb/lagom/matrix.c                                                        In file included from <command-line>:0:0:
./keyboards/sthlmkb/lagom/keymaps/vial/config.h:6:0: error: "ENCODERS_PAD_A" redefined [-Werror]
 #define ENCODERS_PAD_A { C6, F5 }
 ^
In file included from <command-line>:0:0:
./.build/obj_sthlmkb_lagom_vial/src/info_config.h:57:0: note: this is the location of the previous definition
 #    define ENCODERS_PAD_A { D4, F4 }
 ^
In file included from <command-line>:0:0:
./keyboards/sthlmkb/lagom/keymaps/vial/config.h:7:0: error: "ENCODERS_PAD_B" redefined [-Werror]
 #define ENCODERS_PAD_B { D4, F4 }
 ^
In file included from <command-line>:0:0:
./.build/obj_sthlmkb_lagom_vial/src/info_config.h:61:0: note: this is the location of the previous definition
 #    define ENCODERS_PAD_B { C6, F5 }
 ^
cc1: all warnings being treated as errors
 [ERRORS]
 |
 |
 |
gmake[1]: *** [builddefs/common_rules.mk:361: .build/obj_sthlmkb_lagom_vial/matrix.o] Error 1
Make finished with errors
gmake: *** [Makefile:392: sthlmkb/lagom:vial:flash] Error 1
```

Commenting out the `ENCODERS_PAD_A` and B definition lets it at least build without errors but I'm not sure it works, as the keyboard is not recognized by VIAL.

mohoyt, 2023-11-09:
A couple things:
- Are you building with the vial fork of qmk?
- I think the error is caused by conflicting definitions of which is encoder pad A and encoder pad B, try swapping the values in one of the places so they match and hopefully it will go away.

tonykakuuu, 2023-11-09:
I am now (I wasn't aware this fork existed or that your config files are
related to that). It does build now, even with the encoder definitions as
they were, but the keyboard isn't recognized by either VIAL web or the
dedicated application. This may be a problem with my setup or related to
Helios/rp2040, which I need to rule out first.

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

mohoyt, 2023-11-09:
Great! Yeah - vial only works if you compile using vial-qmk. Does the keyboard work with the new vial flashed firmware, but only not get recognised by vial? Just trying to understand where the issue lies.

tonykakuuu, 2023-11-10:
Thanks, everything works, it was a problem with my build environment after all. If possible, could you add a reference to the vial--qmk fork on the firmware README page? This would perhaps help others in a similar situation.

mohoyt, 2023-11-10:
No worries - the build envs can be tricky to set up for the first time! Will make a note of it on the read me. ✅

Closed 2023-11-10.

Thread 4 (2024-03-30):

nice!nano

jonasradke, 2024-03-30:
Hey,
How would I get a nice!nano working with this?

jonasradke, 2024-03-30:
managed to get zmk working based on nibble keyboard config

M13G, 2024-09-28:
@jonasradke hey man is the firmware available on your github and does the firmware allow you to use your keyboard's functions fully like the oled display and those two rotary encoders?

jonasradke, 2024-09-28:
Yes you can look at my radiance repository and base ur config of that.

fkpwolf, 2025-01-23:
@jonasradke I used your firmware in Actions but looks no keyboard appears after flashing. I have [this SuperMini NRF52840](https://github.com/joric/nrfmicro/wiki/Alternatives#supermini-nrf52840). It is said `Works in ZMK as nice_nano_v2`.

jonasradke, 2025-01-23:
[firmware.zip](https://github.com/user-attachments/files/18520126/firmware.zip)

try using this firmware. Have you looked into zmk Studio? I have not really configured it to work yet but will do in the future when my exams are over. Just message me directly or open an issue on my repo so I can help you better.

Closed 2024-03-30.

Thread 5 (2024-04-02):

Generating Custom UF2 File for RP2040 Pro Micro

pioz, 2024-04-02:
I am currently working on customizing the QMK firmware for a Lagom that utilizes the RP2040 style Pro Micro. However, I've encountered an issue where, after compiling the firmware, I only obtain a `.hex` file. For my keyboard, I require a `.uf2` file which is compatible with the RP2040's bootloader.

Could someone guide me on the necessary changes or steps needed to compile the firmware specifically for generating a `.uf2` file suitable for an RP2040 style Pro Micro? Any advice or direction on this matter would be greatly appreciated as I am unsure of the modifications needed to achieve this.

Thank you in advance for your help and time.

mohoyt, 2024-04-02:
Absolutely able to help! There are (at least) two ways. The easiest is using the convert feature in QMK: https://docs.qmk.fm/#/feature_converters?id=overview when you compile your firmware and you append a `-e convert_to=XXXX` to the end of the compile command with the rp2040 controller of your choice.

Another way would be to set up the base keyboard as a rp2040 board (some details here: https://docs.qmk.fm/#/platformdev_rp2040) but I think the first option should be easier and sufficient.

Let me know how you get on!

pioz, 2024-04-03:
It would be nice to include this information in the guide for compiling firmware for the RP2040 micro as well. May be in this guide https://github.com/mohoyt/lagom/blob/main/flash_guide.md

mohoyt, 2024-04-03:
Good idea! Will add that now.

mohoyt, 2024-04-03:
Done! Updated https://github.com/mohoyt/lagom/blob/main/flash_guide.md and https://github.com/mohoyt/lagom/blob/main/firmware/ with more info about rp2040

Closed 2024-04-03.

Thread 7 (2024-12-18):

ProMicro RP2040 dont work

pioz, 2024-12-18:
Hi, I've a Lagom with a ATmega and works perfectly.
Now, I've switch with a new RP2040 (photo to see my setup).

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

In the new micro RP2040 I've installed this firmware: https://github.com/mohoyt/lagom/releases/download/v1.0.2/sthlmkb_lagom_vial-bongocat_helios.uf2

Unfortunately, many of the keys are not functioning, and some keys print two characters instead of one. However, the mini OLED display works fine. Essentially, the keyboard does not work with the new microcontroller.

Did I miss something? Why am I encountering this issue? I also tested it with another Helios, and I encountered the same problem. Please help!

mohoyt, 2024-12-18:
Hey Enrico,

That's super strange! I think I tested it with the same controller so hopefully it's not the firmware.

Is there a pattern to the keys that don't work or are doubled up when you press? That might give us a clue on where to look for issues.

pioz, 2024-12-18:
Sure, here my report:
```
8 -> 8 0
9 -> 9 -
i -> i p
o -> o [
] -> ]
\ -> \
k -> k ;
l -> l '
m -> m .
, -> , /
RETURN -> RETURN MUTE
UP -> UP
DOWN -> DOWN
LEFT -> LEFT RIGHT
```
Right rotary change volume, no click work

All other keys does nothing.

pioz, 2024-12-18:
I've also tried with https://github.com/0xCB-dev/0xCB-Helios and I have same output.

mohoyt, 2024-12-19:
Interesting! Sounds like there's some sort of short or interaction between cols 8 and 10 and 9 and 11 on the top IC. But strange that this doesn't happen on the Atmel pro micro. That still works if you plug it back in again right?

If you have a multi-meter can you see that the both ICs are getting power when the board is powered (pin 16 (top left of each IC) should be 3.3 to 5v) and that there are no shorts between the IC pins on the top row?

And does it work fine in Vial when you open it to configure the keymap?

pioz, 2024-12-19:
If I put back the Atmel all works perfectly. I don't have in home a multi-meter. But I can borrow it to try.

pioz, 2024-12-24:
@mohoyt Since I am not an expert in electronics, could you kindly tell me the voltage I should expect on each pin in the image by placing the positive probe of the multimeter on the pin and the negative probe on a GND pin?  Specifically, I am also interested in the pins of the SN74HC138N demultiplexer ICs.

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

pioz, 2024-12-24:
Ok thanks very much! 🙏🏻 How can I check the continuity from the pins to check if they are connected together?

mohoyt, 2024-12-24:
Depending on the multimeter that you're testing with it might have a continuity mode (that would beep if there's a connection) but you can always set it to a resistance mode like 2000 ohms and then measure to see if there is a connection.

If there's a connection and therefore continuity it will read 0, otherwise it will likely be max or 1 if there's not continuity. And you want to do this with the board disconnected from the computer.

mohoyt, 2024-12-26:
Do you have an LED strip installed? Is there a way that you could temporarily disconnect it to see if that might be the issue? It could be drawing too much current from the microcontroller causing it to crash/behave flakily.

pioz, 2024-12-26:
Yes, but I've already tried to remove the strip led. The problem persist.

mohoyt, 2024-12-26:
I'm really struggling to think what it might be then. I will build up a board with this microcontroller later today to see if I get the same behaviour, but I'm fairly sure that it worked fine before when I created this firmware.

Long shot, but are you sure that the rp2040 controllers are working 100%? Do you have another board or another way of testing that all the IO is working on them?

pioz, 2024-12-26:
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

Sure! Here’s an improved version:

I’ve been using the ATmega for months without any issues. However, the RP2040 isn’t working as expected as described before. I’ve ordered another board to start building a new keyboard from scratch. I’ll keep you updated.

MisanZx, 2024-12-28:
Hi there all, I have same issue of doubling keys on the right hand side of the keyboard. left hand side does not work. oled is working fine.

mohoyt, 2024-12-29:
Hey @MisanZx - Have you had a look at the debugging guide here: https://sthlmkb.com/2023/06/debugging-your-keyboard/

There might be an issue with the ICs, have you tried swapping them to see if that changes the behaviour?

pioz, 2025-01-03:
The new PCB has just arrived. I tested continuity on the bare board with a multimeter, and everything checks out except for pin F4 (encC), which seems to be disconnected. Is this expected? According to the schematic, pin F4 should be connected to the encC hole (the top-right hole on the PCB).

I've attached a video, please make sure to play it with audio enabled:

https://github.com/user-attachments/assets/e92f5456-bb6f-4df8-9944-d8ab7c2e9947

pioz, 2025-01-03:
Looking closely at the underside, there's a scratch, could that be the cause?

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

MisanZx, 2025-01-03:
I dont have any spare IC's I did swap them over to see if the other half works, no change.

mohoyt, 2025-01-04:
@pioz That scratch could well be the cause. Pin F4 is only connected to that specific encoder pin and nothing else. So if it's not working then it's likely something on that trace.

I wouldn't continue building that PCB then as you won't have a working encoder there unless you add a bodge wire (though a switch at that location would still work fine). Would you like me to send out a replacement right away for you?

mohoyt, 2025-01-04:
@MisanZx Would you be able to reach out to hej@sthlmkb.com and we can send you some replacement ICs to swap in to hopefully solve your problem (or at least diagnose a little better what is happening) 😅

pioz, 2025-01-04:
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

Yes please 🙏🏻

MisanZx, 2025-01-04:
@mohoyt no worries, thanks for the offer, I accidentally broke my own pcb board somewhere else now. Assuming it was the cheap microcontroller that was not very good as it was exactly the same one @pioz has. Thanks for your help anyways. I am building the board again with another friend soon but with a different micro controller so I should not run into any issues.

mohoyt, 2025-01-04:
@pioz will send that first thing Tuesday (as Monday is a holiday here) - hope it won't be too long a wait!

@MisanZx hopefully the other build goes better, but let me know if there are any issues and maybe I can help!

pioz, 2025-01-15:
I've just finished building the new Lagom keyboard. I can finally say that everything works very well with the Pro Micro ATMega, RP2040, and also with [0xCB-Helios](https://github.com/0xCB-dev/0xCB-Helios). 💪🏻🍺"

Thanks @mohoyt for your help and support.

Closed 2025-01-15.

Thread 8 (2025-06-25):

Fireware does not compile with current QMK

Jerakin, 2025-06-25:
Get this error.

Am I missing a step in the documentation?

```sh
[Jerakin@DESKTOP-J0TTDOO qmk_firmware]$ make lagom:default
QMK Firmware 0.29.8
⚠ lagom: Build marker "keyboard.json" not found.
☒ lagom: LAYOUT_base: Layout macro should not be defined within ".h" files.
☒ lagom: LAYOUT_splits: Layout macro should not be defined within ".h" files.
☒ lagom: LAYOUT_iso: Layout macro should not be defined within ".h" files.
☒ lagom: LAYOUT_split_space: Layout macro should not be defined within ".h" files.
☒ lagom: LAYOUT_7u_space: Layout macro should not be defined within ".h" files.
Making lagom with keymap default

⚠ lagom: Build marker "keyboard.json" not found.
☒ lagom: LAYOUT_base: Layout macro should not be defined within ".h" files.
☒ lagom: LAYOUT_splits: Layout macro should not be defined within ".h" files.
☒ lagom: LAYOUT_iso: Layout macro should not be defined within ".h" files.
☒ lagom: LAYOUT_split_space: Layout macro should not be defined within ".h" files.
☒ lagom: LAYOUT_7u_space: Layout macro should not be defined within ".h" files.
⚠ lagom: Build marker "keyboard.json" not found.
☒ lagom: LAYOUT_base: Layout macro should not be defined within ".h" files.
☒ lagom: LAYOUT_splits: Layout macro should not be defined within ".h" files.
☒ lagom: LAYOUT_iso: Layout macro should not be defined within ".h" files.
☒ lagom: LAYOUT_split_space: Layout macro should not be defined within ".h" files.
☒ lagom: LAYOUT_7u_space: Layout macro should not be defined within ".h" files.
avr-gcc.exe (GCC) 14.2.0
Copyright (C) 2024 Free Software Foundation, Inc.
This is free software; see the source for copying conditions.  There is NO
warranty; not even for MERCHANTABILITY or FITNESS FOR A PARTICULAR PURPOSE.

Compiling: keyboards/lagom/matrix.c                                                                In file included from <command-line>:
./keyboards/lagom/config.h:20:10: fatal error: config_common.h: No such file or directory
   20 | #include "config_common.h"
      |          ^~~~~~~~~~~~~~~~~
compilation terminated.
 [ERRORS]
 |
 |
 |
make[1]: *** [builddefs/common_rules.mk:362: .build/obj_lagom_default/matrix.o] Error 1
Make finished with errors
make: *** [Makefile:428: lagom:default] Error 1

```

Jerakin, 2025-06-26:
Using the firmware that ships within the QMK repository it compiles without problems. It does not have all the keymaps this repository does, but they should be trivial to port over.

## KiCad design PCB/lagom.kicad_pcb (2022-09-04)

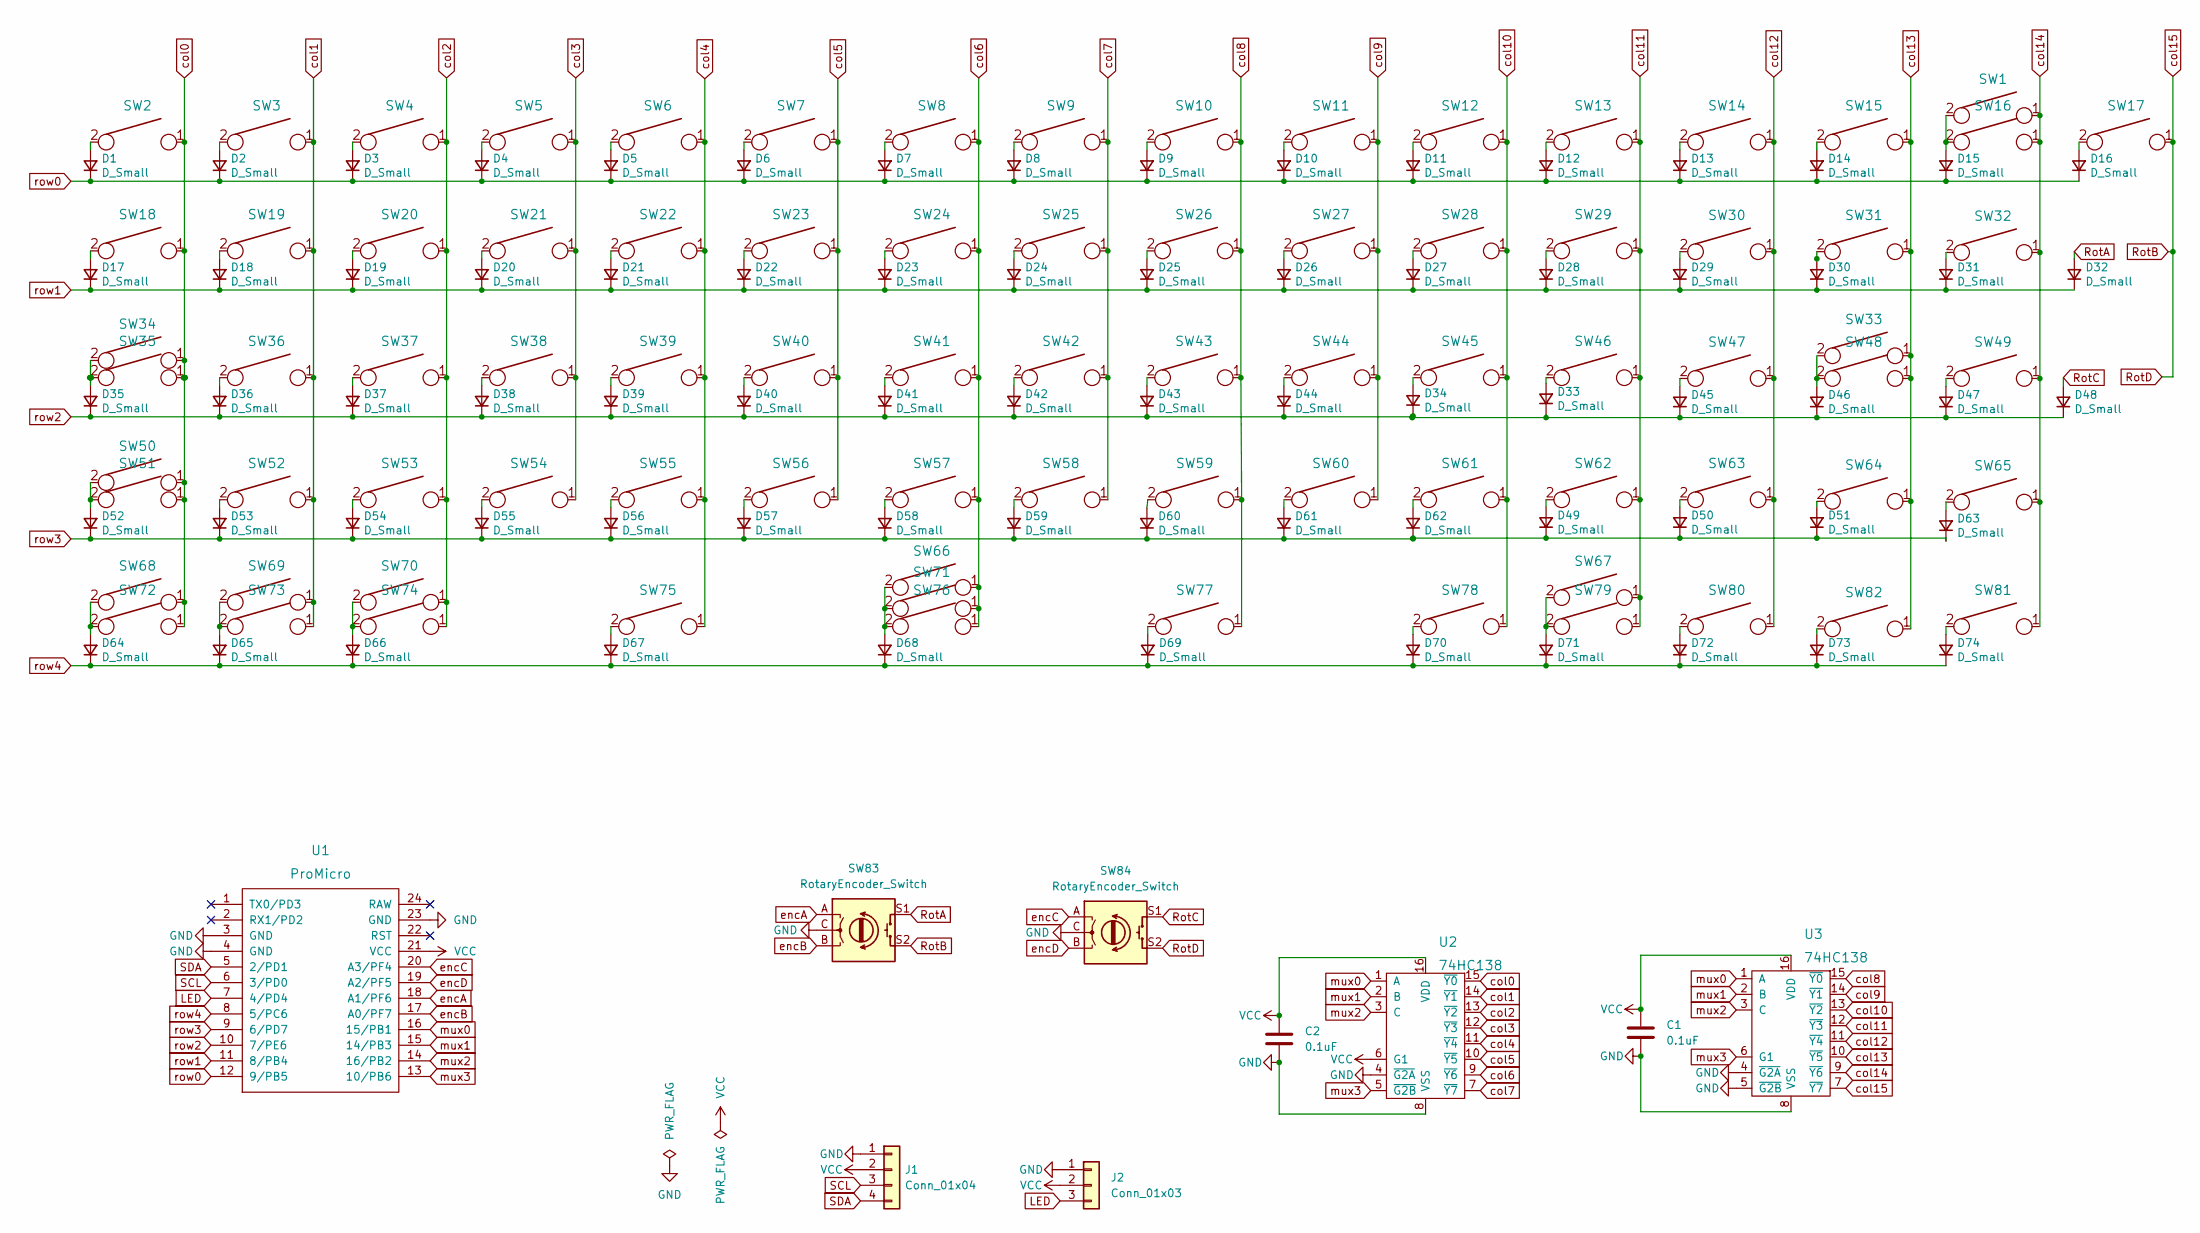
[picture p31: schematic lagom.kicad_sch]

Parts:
C1, C2: 0.1uF; C_Disc_D4.7mm_W2.5mm_P5.00mm
D1: D_Small; D_DO-35_SOD27_P7.62mm_Horizontal
D2, D3, D4, D5, D6, D7, D8, D9, D10, D11, D12, D13, D14, D15, D16, D17, D18, D19, D20, D21, D22, D23, D24, D25, D26, D27, D28, D29, D30, D31, D32, D33, D34, D35, D36, D37, D38, D39, D40, D41, D42, D43, D44, D45, D46, D47, D48, D49, D50, D51, D52, D53, D54, D55, D56, D57, D58, D59, D60, D61, D62, D63, D64, D65, D66, D67, D68, D69, D70, D71, D72, D73, D74: D_Small; D_DO-34_SOD68_P7.62mm_Horizontal
J1: Conn_01x04; PinSocket_1x04_P2.54mm_Vertical
J2: Conn_01x03; PinSocket_1x03_P2.54mm_Vertical
SW1: KEYSW; SW_Cherry_MX_2.00u_PCB
SW2, SW3, SW4, SW5, SW6, SW7, SW8, SW9, SW10, SW11, SW12, SW13, SW14, SW15, SW16, SW17, SW19, SW20, SW21, SW22, SW23, SW24, SW25, SW26, SW27, SW28, SW29, SW30, SW32, SW35, SW36, SW37, SW38, SW39, SW40, SW41, SW42, SW43, SW44, SW45, SW46, SW47, SW49, SW52, SW53, SW54, SW55, SW56, SW57, SW58, SW59, SW60, SW61, SW62, SW64, SW65, SW73, SW80, SW81, SW82: KEYSW; SW_Cherry_MX_1.00u_PCB
SW18: KEYSW; SW_Cherry_MX_1.50u_Plate
SW31, SW67, SW70, SW72: KEYSW; SW_Cherry_MX_1.50u_PCB
SW33: KEYSW; SW_Cherry_MX_ISOEnter_PCB
SW34, SW63: KEYSW; SW_Cherry_MX_1.75u_PCB
SW48, SW50, SW75: KEYSW; SW_Cherry_MX_2.25u_PCB
SW51, SW68, SW69, SW71, SW74, SW78, SW79: KEYSW; SW_Cherry_MX_1.25u_PCB
SW66: KEYSW; SW_Cherry_MX_7u_PCB
SW76: KEYSW; SW_Cherry_MX_6.25u_PCB
SW77: KEYSW; SW_Cherry_MX_2.75u_PCB
SW83, SW84: RotaryEncoder_Switch; RotaryEncoder_EC11
U1: ProMicro; ArduinoProMicro-ZigZag
U2, U3: 74HC138; DIP-16_W7.62mm_Socket

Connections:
GND: C1.2, C2.2, J1.1, J2.1, SW83.C, SW84.C, U1.3 (GND), U1.4 (GND), U1.23 (GND), U2.4 (~G2A), U2.8 (VSS), U3.4 (~G2A), U3.5 (~G2B), U3.8 (VSS)
LED: J2.3, U1.7 (4/PD4)
unnamed: D1.2 (A), SW2.2
unnamed: D2.2 (A), SW3.2
unnamed: D3.2 (A), SW4.2
unnamed: D4.2 (A), SW5.2
unnamed: D5.2 (A), SW6.2
unnamed: D6.2 (A), SW7.2
unnamed: D7.2 (A), SW8.2
unnamed: D8.2 (A), SW9.2
unnamed: D9.2 (A), SW10.2
unnamed: D10.2 (A), SW11.2
unnamed: D11.2 (A), SW12.2
unnamed: D12.2 (A), SW13.2
unnamed: D13.2 (A), SW14.2
unnamed: D14.2 (A), SW15.2
unnamed: D15.2 (A), SW1.2, SW16.2
unnamed: D16.2 (A), SW17.2
unnamed: D17.2 (A), SW18.2
unnamed: D18.2 (A), SW19.2
unnamed: D19.2 (A), SW20.2
unnamed: D20.2 (A), SW21.2
unnamed: D21.2 (A), SW22.2
unnamed: D22.2 (A), SW23.2
unnamed: D23.2 (A), SW24.2
unnamed: D24.2 (A), SW25.2
unnamed: D25.2 (A), SW26.2
unnamed: D26.2 (A), SW27.2
unnamed: D27.2 (A), SW28.2
unnamed: D28.2 (A), SW29.2
unnamed: D29.2 (A), SW30.2
unnamed: D30.2 (A), SW31.2
unnamed: D31.2 (A), SW32.2
unnamed: D33.2 (A), SW46.2
unnamed: D34.2 (A), SW45.2
unnamed: D35.2 (A), SW34.2, SW35.2
unnamed: D36.2 (A), SW36.2
unnamed: D37.2 (A), SW37.2
unnamed: D38.2 (A), SW38.2
unnamed: D39.2 (A), SW39.2
unnamed: D40.2 (A), SW40.2
unnamed: D41.2 (A), SW41.2
unnamed: D42.2 (A), SW42.2
unnamed: D43.2 (A), SW43.2
unnamed: D44.2 (A), SW44.2
unnamed: D45.2 (A), SW47.2
unnamed: D46.2 (A), SW33.2, SW48.2
unnamed: D47.2 (A), SW49.2
unnamed: D49.2 (A), SW62.2
unnamed: D50.2 (A), SW63.2
unnamed: D51.2 (A), SW64.2
unnamed: D52.2 (A), SW50.2, SW51.2
unnamed: D53.2 (A), SW52.2
unnamed: D54.2 (A), SW53.2
unnamed: D55.2 (A), SW54.2
unnamed: D56.2 (A), SW55.2
unnamed: D57.2 (A), SW56.2
unnamed: D58.2 (A), SW57.2
unnamed: D59.2 (A), SW58.2
unnamed: D60.2 (A), SW59.2
unnamed: D61.2 (A), SW60.2
unnamed: D62.2 (A), SW61.2
unnamed: D63.2 (A), SW65.2
unnamed: D64.2 (A), SW68.2, SW72.2
unnamed: D65.2 (A), SW69.2, SW73.2
unnamed: D66.2 (A), SW70.2, SW74.2
unnamed: D67.2 (A), SW75.2
unnamed: D68.2 (A), SW66.2, SW71.2, SW76.2
unnamed: D69.2 (A), SW77.2
unnamed: D70.2 (A), SW78.2
unnamed: D71.2 (A), SW67.2, SW79.2
unnamed: D72.2 (A), SW80.2
unnamed: D73.2 (A), SW82.2
unnamed: D74.2 (A), SW81.2
RotA: D32.2 (A), SW83.S1
RotB: SW17.1, SW83.S2, SW84.S2, U3.7 (~Y7)
RotC: D48.2 (A), SW84.S1
SCL: J1.3, U1.6 (3/PD0)
SDA: J1.4, U1.5 (2/PD1)
VCC: C1.1, C2.1, J1.2, J2.2, U1.21 (VCC), U2.6 (G1), U2.16 (VDD), U3.16 (VDD)
col0: SW2.1, SW18.1, SW34.1, SW35.1, SW50.1, SW51.1, SW68.1, SW72.1, U2.15 (~Y0)
col1: SW3.1, SW19.1, SW36.1, SW52.1, SW69.1, SW73.1, U2.14 (~Y1)
col2: SW4.1, SW20.1, SW37.1, SW53.1, SW70.1, SW74.1, U2.13 (~Y2)
col3: SW5.1, SW21.1, SW38.1, SW54.1, U2.12 (~Y3)
col4: SW6.1, SW22.1, SW39.1, SW55.1, SW75.1, U2.11 (~Y4)
col5: SW7.1, SW23.1, SW40.1, SW56.1, U2.10 (~Y5)
col6: SW8.1, SW24.1, SW41.1, SW57.1, SW66.1, SW71.1, SW76.1, U2.9 (~Y6)
col7: SW9.1, SW25.1, SW42.1, SW58.1, U2.7 (~Y7)
col8: SW10.1, SW26.1, SW43.1, SW59.1, SW77.1, U3.15 (~Y0)
col9: SW11.1, SW27.1, SW44.1, SW60.1, U3.14 (~Y1)
col10: SW12.1, SW28.1, SW45.1, SW61.1, SW78.1, U3.13 (~Y2)
col11: SW13.1, SW29.1, SW46.1, SW62.1, SW67.1, SW79.1, U3.12 (~Y3)
col12: SW14.1, SW30.1, SW47.1, SW63.1, SW80.1, U3.11 (~Y4)
col13: SW15.1, SW31.1, SW33.1, SW48.1, SW64.1, SW82.1, U3.10 (~Y5)
col14: SW1.1, SW16.1, SW32.1, SW49.1, SW65.1, SW81.1, U3.9 (~Y6)
encA: SW83.A, U1.18 (A1/PF6)
encB: SW83.B, U1.17 (A0/PF7)
encC: SW84.A, U1.20 (A3/PF4)
encD: SW84.B, U1.19 (A2/PF5)
mux0: U1.16 (15/PB1), U2.1 (A), U3.1 (A)
mux1: U1.15 (14/PB3), U2.2 (B), U3.2 (B)
mux2: U1.14 (16/PB2), U2.3 (C), U3.3 (C)
mux3: U1.13 (10/PB6), U2.5 (~G2B), U3.6 (G1)
row0: D1.1 (K), D2.1 (K), D3.1 (K), D4.1 (K), D5.1 (K), D6.1 (K), D7.1 (K), D8.1 (K), D9.1 (K), D10.1 (K), D11.1 (K), D12.1 (K), D13.1 (K), D14.1 (K), D15.1 (K), D16.1 (K), U1.12 (9/PB5)
row1: D17.1 (K), D18.1 (K), D19.1 (K), D20.1 (K), D21.1 (K), D22.1 (K), D23.1 (K), D24.1 (K), D25.1 (K), D26.1 (K), D27.1 (K), D28.1 (K), D29.1 (K), D30.1 (K), D31.1 (K), D32.1 (K), U1.11 (8/PB4)
row2: D33.1 (K), D34.1 (K), D35.1 (K), D36.1 (K), D37.1 (K), D38.1 (K), D39.1 (K), D40.1 (K), D41.1 (K), D42.1 (K), D43.1 (K), D44.1 (K), D45.1 (K), D46.1 (K), D47.1 (K), D48.1 (K), U1.10 (7/PE6)
row3: D49.1 (K), D50.1 (K), D51.1 (K), D52.1 (K), D53.1 (K), D54.1 (K), D55.1 (K), D56.1 (K), D57.1 (K), D58.1 (K), D59.1 (K), D60.1 (K), D61.1 (K), D62.1 (K), D63.1 (K), U1.9 (6/PD7)
row4: D64.1 (K), D65.1 (K), D66.1 (K), D67.1 (K), D68.1 (K), D69.1 (K), D70.1 (K), D71.1 (K), D72.1 (K), D73.1 (K), D74.1 (K), U1.8 (5/PC6)

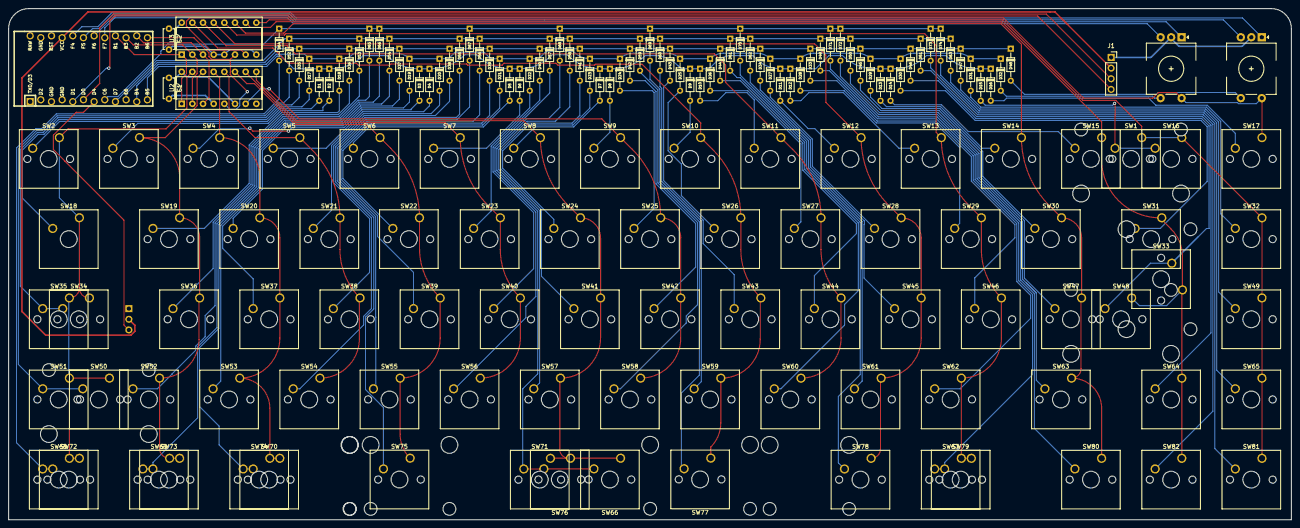
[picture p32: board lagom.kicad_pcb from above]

Board: 2 copper layers, 305.6 x 121.8 mm, 165 parts (1 on the bottom side), 108 nets.

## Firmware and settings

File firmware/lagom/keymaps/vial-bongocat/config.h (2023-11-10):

#pragma once

#define VIAL_KEYBOARD_UID {0x8C, 0x59, 0x2E, 0xF7, 0xBA, 0x40, 0xCC, 0xCA}

#define ENCODERS_PAD_A { C6, F5 }
#define ENCODERS_PAD_B { D4, F4 }

#define VIAL_COMBO_ENTRIES 2
#define VIAL_TAP_DANCE_ENTRIES 4
#define VIAL_KEY_OVERRIDE_ENTRIES 2
#define DYNAMIC_KEYMAP_LAYER_COUNT 2
#define VIAL_UNLOCK_COMBO_ROWS { 0, 4 }
#define VIAL_UNLOCK_COMBO_COLS { 0, 14 }
#define VIAL_ENCODER_DEFAULT { KC_VOLD, KC_VOLU, KC_MPRV, KC_MNXT, KC_TRNS, KC_TRNS, KC_TRNS, KC_TRNS }

// OLED setup for bongocat
#define IDLE_FRAMES 5
#define IDLE_SPEED 30
#define TAP_FRAMES 2
#define TAP_SPEED 40
#define ANIM_FRAME_DURATION 200
#define ANIM_SIZE 512

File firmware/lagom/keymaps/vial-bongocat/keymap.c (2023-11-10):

/* Copyright 2022 mohoyt
 *
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
 * You should have received a copy of the GNU General Public License
 * along with this program.  If not, see <http://www.gnu.org/licenses/>.
 */
#include QMK_KEYBOARD_H
#include <stdio.h>

static long int oled_timeout = 600000; // 10 minutes
bool gui_on = true;
char wpm_str[10];
uint32_t anim_timer = 0;
uint32_t anim_sleep = 0;
uint8_t current_idle_frame = 0;
uint8_t current_tap_frame = 0;

const uint16_t PROGMEM keymaps[][MATRIX_ROWS][MATRIX_COLS] = {
  [0] = LAYOUT_base(
    KC_ESC,  KC_1,    KC_2,    KC_3,    KC_4,    KC_5,    KC_6,    KC_7,    KC_8,    KC_9,    KC_0,    KC_MINS, KC_EQL,  KC_BSPC, KC_HOME,
    KC_TAB,  KC_Q,    KC_W,    KC_E,    KC_R,    KC_T,    KC_Y,    KC_U,    KC_I,    KC_O,    KC_P,    KC_LBRC, KC_RBRC, KC_BSLS, KC_END, KC_MPLY,
    KC_CAPS, KC_A,    KC_S,    KC_D,    KC_F,    KC_G,    KC_H,    KC_J,    KC_K,    KC_L,    KC_SCLN, KC_QUOT,          KC_ENT,  KC_PGUP,KC_MUTE,
    LSFT_T(KC_GRV),   KC_Z,    KC_X,    KC_C,    KC_V,    KC_B,    KC_N,    KC_M,    KC_COMM, KC_DOT,  KC_SLSH, KC_RSFT, KC_UP,   KC_PGDN,
    KC_LCTL, KC_LGUI, KC_LALT,                            KC_SPC,                             KC_RALT,   MO(1), KC_LEFT, KC_DOWN, KC_RGHT ),

  [1] = LAYOUT_base(
  	KC_TRNS, KC_F1,   KC_F2,   KC_F3,   KC_F4,   KC_F5,   KC_F6,   KC_F7,   KC_F8,   KC_F9,   KC_F10,  KC_F11, KC_F12,  KC_DEL, KC_HOME,
    KC_TRNS, KC_TRNS, KC_TRNS, KC_TRNS, KC_TRNS, KC_TRNS, KC_TRNS, KC_TRNS, KC_TRNS, KC_TRNS, KC_TRNS, KC_TRNS, KC_TRNS, KC_TRNS, KC_TRNS, KC_TRNS,
    KC_TRNS, KC_TRNS, KC_TRNS, KC_TRNS, KC_TRNS, KC_TRNS, KC_TRNS, KC_TRNS, KC_TRNS, KC_TRNS, KC_TRNS, KC_TRNS,          KC_TRNS, KC_TRNS, KC_MUTE,
    KC_TRNS, KC_TRNS, KC_TRNS, KC_TRNS, KC_TRNS, KC_TRNS, KC_TRNS, KC_TRNS, KC_TRNS, KC_TRNS, KC_TRNS, KC_TRNS, KC_UP,   KC_TRNS,
    KC_LCTL, KC_LGUI, KC_LALT,                            KC_SPC,                             KC_RALT, KC_RCTL, KC_LEFT, KC_DOWN, KC_RGHT )
};

//Encoder map
#if defined(ENCODER_MAP_ENABLE)
const uint16_t PROGMEM encoder_map[][2][2] = {
    [0] =   { ENCODER_CCW_CW(KC_MPRV, KC_MNXT), ENCODER_CCW_CW(KC_VOLD, KC_VOLU)  },
    [1] =  { ENCODER_CCW_CW(KC_MPRV, KC_MNXT), ENCODER_CCW_CW(KC_VOLD, KC_VOLU)  }
};
#endif

//OLED stuff here
#ifdef OLED_ENABLE
oled_rotation_t oled_init_user(oled_rotation_t rotation) {
   return OLED_ROTATION_180;  // flips the display 180 degrees
}

static void render_anim(void) {

    // Idle animation
    static const char PROGMEM idle[IDLE_FRAMES][ANIM_SIZE] = {

        {
            0,0,0,0,0,0,0,0,0,0,0,0,0,0,0,0,0,0,0,0,0,0,0,0,0,0,0,0,0,0,0,0,0,0,0,0,0,0,0,0,0,0,0,0,0,0,0,0,0,0,0,0,0,0,0,0,0,0,128,64,64,32,32,32,32,16,16,16,16,16,8,8,4,4,4,8,48,64,128,0,0,0,0,0,0,0,0,0,0,0,0,0,0,0,0,0,0,0,0,0,0,0,0,0,0,0,0,0,0,0,0,0,0,0,0,0,0,0,0,0,0,0,0,0,0,128,128,128,0,0,0,0,0,0,0,0,0,0,0,0,0,0,0,0,0,0,0,0,0,0,0,0,0,0,0,0,0,0,0,0,0,0,0,0,0,0,0,0,0,0,0,0,0,0,0,0,0,24,100,130,2,2,2,2,2,1,0,0,0,0,128,128,0,0,0,0,0,0,0,0,0,128,0,48,48,0,192,193,193,194,4,8,16,32,64,128,0,0,0,128,128,128,128,64,64,
            64,64,32,32,32,32,16,16,16,16,8,8,8,8,8,4,4,4,4,4,2,2,2,2,1,1,1,1,0,0,0,0,0,0,0,0,0,0,0,0,0,0,0,0,0,0,0,0,0,0,0,0,0,0,0,0,0,0,0,0,0,0,0,0,0,0,0,0,0,0,0,0,0,0,0,0,0,0,0,192,56,4,3,0,0,0,0,0,0,0,12,12,12,13,1,0,64,160,33,34,18,17,17,17,9,8,8,8,8,4,4,8,8,16,16,16,16,16,17,15,1,1,0,0,0,0,0,0,0,0,0,0,0,0,0,0,0,0,0,0,0,0,0,0,0,0,0,0,0,0,0,0,0,0,0,0,0,0,0,0,0,0,0,0,0,0,0,0,0,0,0,0,0,0,0,0,128,128,128,128,128,64,64,64,64,64,32,32,32,32,32,16,16,16,16,16,8,8,8,8,8,4,4,4,4,4,2,3,2,2,1,1,1,1,1,1,2,2,4,4,8,8,8,8,8,7,
            0,0,0,0,0,0,0,0,0,0,0,0,0,0,0,0,0,0,0,0,0,0,0,0,0,0,0,0,0,0,0,0,0,0,0,0,0,0,0,0,0,0,0,0,0,0,0,0,0,0,0,0,0,0,0,0,0,0,0,0,0
        },

        {
            0,0,0,0,0,0,0,0,0,0,0,0,0,0,0,0,0,0,0,0,0,0,0,0,0,0,0,0,0,0,0,0,0,0,0,0,0,0,0,0,0,0,0,0,0,0,0,0,0,0,0,0,0,0,0,0,0,0,128,64,64,32,32,32,32,16,16,16,16,16,8,8,4,4,4,8,48,64,128,0,0,0,0,0,0,0,0,0,0,0,0,0,0,0,0,0,0,0,0,0,0,0,0,0,0,0,0,0,0,0,0,0,0,0,0,0,0,0,0,0,0,0,0,0,0,128,128,128,0,0,0,0,0,0,0,0,0,0,0,0,0,0,0,0,0,0,0,0,0,0,0,0,0,0,0,0,0,0,0,0,0,0,0,0,0,0,0,0,0,0,0,0,0,0,0,0,0,24,100,130,2,2,2,2,2,1,0,0,0,0,128,128,0,0,0,0,0,0,0,0,0,128,0,48,48,0,192,193,193,194,4,8,16,32,64,128,0,0,0,128,128,128,128,64,64,
            64,64,32,32,32,32,16,16,16,16,8,8,8,8,8,4,4,4,4,4,2,2,2,2,1,1,1,1,0,0,0,0,0,0,0,0,0,0,0,0,0,0,0,0,0,0,0,0,0,0,0,0,0,0,0,0,0,0,0,0,0,0,0,0,0,0,0,0,0,0,0,0,0,0,0,0,0,0,0,192,56,4,3,0,0,0,0,0,0,0,12,12,12,13,1,0,64,160,33,34,18,17,17,17,9,8,8,8,8,4,4,8,8,16,16,16,16,16,17,15,1,1,0,0,0,0,0,0,0,0,0,0,0,0,0,0,0,0,0,0,0,0,0,0,0,0,0,0,0,0,0,0,0,0,0,0,0,0,0,0,0,0,0,0,0,0,0,0,0,0,0,0,0,0,0,0,128,128,128,128,128,64,64,64,64,64,32,32,32,32,32,16,16,16,16,16,8,8,8,8,8,4,4,4,4,4,2,3,2,2,1,1,1,1,1,1,2,2,4,4,8,8,8,8,8,
            7,0,0,0,0,0,0,0,0,0,0,0,0,0,0,0,0,0,0,0,0,0,0,0,0,0,0,0,0,0,0,0,0,0,0,0,0,0,0,0,0,0,0,0,0,0,0,0,0,0,0,0,0,0,0,0,0,0,0,0,0,0
        },

        {
            0,0,0,0,0,0,0,0,0,0,0,0,0,0,0,0,0,0,0,0,0,0,0,0,0,0,0,0,0,0,0,0,0,0,0,0,0,0,0,0,0,0,0,0,0,0,0,0,0,0,0,0,0,0,0,0,0,0,0,128,128,64,64,64,64,32,32,32,32,16,8,4,2,2,4,24,96,128,0,0,0,0,0,0,0,0,0,0,0,0,0,0,0,0,0,0,0,0,0,0,0,0,0,0,0,0,0,0,0,0,0,0,0,0,0,0,0,0,0,0,0,0,0,0,0,128,128,128,0,0,0,0,0,0,0,0,0,0,0,0,0,0,0,0,0,0,0,0,0,0,0,0,0,0,0,0,0,0,0,0,0,0,0,0,0,0,0,0,0,0,0,0,0,0,0,0,0,60,194,1,1,2,2,4,4,2,1,0,0,0,0,0,0,0,0,0,0,0,0,0,0,0,0,96,96,0,129,130,130,132,8,16,32,64,128,0,0,0,0,128,128,128,128,64,64,64,64,32,
            32,32,32,16,16,16,16,8,8,8,8,8,4,4,4,4,4,2,2,2,2,1,1,1,1,0,0,0,0,0,0,0,0,0,0,0,0,0,0,0,0,0,0,0,0,0,0,0,0,0,0,0,0,0,0,0,0,0,0,0,0,0,0,0,0,0,0,0,0,0,0,0,0,0,0,0,128,112,25,6,0,0,0,0,0,0,0,24,24,24,27,3,0,64,160,34,36,20,18,18,18,11,8,8,8,8,5,5,9,9,16,16,16,16,16,17,15,1,1,0,0,0,0,0,0,0,0,0,0,0,0,0,0,0,0,0,0,0,0,0,0,0,0,0,0,0,0,0,0,0,0,0,0,0,0,0,0,0,0,0,0,0,0,0,0,0,0,0,0,0,0,0,0,128,128,128,128,128,64,64,64,64,64,32,32,32,32,32,16,16,16,16,16,8,8,8,8,8,4,4,4,4,4,2,3,2,2,1,1,1,1,1,1,2,2,4,4,8,8,8,8,8,7,0,0,0,
            0,0,0,0,0,0,0,0,0,0,0,0,0,0,0,0,0,0,0,0,0,0,0,0,0,0,0,0,0,0,0,0,0,0,0,0,0,0,0,0,0,0,0,0,0,0,0,0,0,0,0,0,0,0,0,0,0,0
        },
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

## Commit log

2022-08-01 Init Kicad
    [lagom.kicad_pcb, lagom.kicad_sch]
2022-08-01 Grid started
    [lagom.kicad_sch]
2022-08-06 Matrix almost done
    [lagom.kicad_sch]
2022-08-07 Matrix complete, wiring schematic
    [lagom.kicad_sch]
2022-08-07 Schematic complete
    [lagom.kicad_sch]
2022-08-22 PCB layout done
    [lagom.kicad_pcb, lagom.kicad_sch]
2022-08-29 demux pin change
    [lagom.kicad_sch]
2022-09-03 Layout and diode placement basically done
    [lagom.kicad_pcb, lagom.kicad_sch]
2022-09-04 PCB mostly done
    [lagom.kicad_pcb, lagom.kicad_sch]
2022-10-10 Graphics and plate
    [lagom-plate-orig.dxf, lagom.kicad_sch]
2022-10-15 base, plate and more added
    [lagom_base.kicad_pcb, lagom_base.kicad_sch, lagom_foldable_case.kicad_pcb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]
2022-10-16 Labelling mostly done
    [lagom.kicad_sch, lagom_plate.kicad_pcb, lagom_window.kicad_pcb]
2022-10-17 V1 done
    [lagom-B_Cu.gbl, lagom-B_Mask.gbs, lagom-B_Paste.gbp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]
2022-10-18 Missing holes for tab key
2022-10-18 v1 gerbers updated
    [lagom-B_Cu.gbl, lagom-B_Mask.gbs, lagom-B_Paste.gbp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]
2022-11-10 Working firmware and updated build guide
    [lagom.kicad_sch, lagom_window-Edge_Cuts.dxf, lagom_window.kicad_pcb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]
2022-11-20 Build guide updated to show LED socket
    [lagom-B_Cu.gbl, lagom-B_Mask.gbs, lagom-B_Paste.gbp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]
2022-12-28 Lagom window updated
    [lagom_window-Edge_Cuts.dxf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]
2023-01-10 Updated rotary encoder direction in vial firmware files
2023-08-26 Closeup diode photo added
2023-10-13 PCB readme updated
    [lagom_foldable_case.kicad_pcb, lagom_foldable_case.kicad_sch]
2023-11-04 Update matrix.c
    Make compatible with ARM / rp2040 based boards.

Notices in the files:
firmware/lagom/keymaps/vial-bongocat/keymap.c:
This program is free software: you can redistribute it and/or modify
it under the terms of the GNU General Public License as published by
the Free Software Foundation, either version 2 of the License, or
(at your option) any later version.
